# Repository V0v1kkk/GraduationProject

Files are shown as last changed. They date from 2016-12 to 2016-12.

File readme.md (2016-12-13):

# Разработка аппаратно-программного комплекса для оперативного мониторинга качества воздуха в жилых помещениях
Цель работы – разработать аппаратно-программный комплекс, с помощью которого можно оперативно получать данные о качестве воздуха, параметрах микроклимата, содержании монооксида углерода, двуокиси углерода, взвешенных частиц и природного газа в воздухе жилых помещений.

В процессе работы: 
* Изучена предметная область.
* Рассмотрены аналоги разработанного устройства, представленные на рынке. 
* Произведён выбор датчиков, наиболее подходящих для использования в устройстве, 
    а также рассмотрены вопросы, связанные с получением корректных данных от них. 
* Построена [диаграмма потоков данных](Images/DFD.png).
* Разработана [принципиальная схема устройства](Images/схема.png). 
* Разработаны прошивки для двух микроконтроллеров, 
    входящих в состав устройства (**[1](DataCollector/), [2](MainController/)**). 
* Разработан [графический интерфейс](Images/Интерфейс.png), представленный [ЖК-дисплеем](Nextion/) (**[1](Images/gui/1.png), [2](Images/gui/2.png), [3](Images/gui/3.png), [4](Images/gui/4.png), [5](Images/gui/5.png), [6](Images/gui/6.png), [7](Images/gui/7.png), [8](Images/gui/8.png), [9](Images/gui/9.png), [10](Images/10.png)**) и 
[web-интерфейс](WebInterface/) (**[1](Images/1.png), [2](Images/2.png), [3](Images/3.png), [4](Images/4.png), [5](Images/5.png)**). 
* Написано руководство пользователя. 
* Построен прототип устройства.

## [Пояснительная записка](Text/Диплом.pdf)

## Видео
Прототип в работе (https://www.youtube.com/watch?v=i2k4qLWkXlE)

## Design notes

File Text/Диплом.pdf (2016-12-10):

Министерство образования и науки Российской Федерации ФГАОУ ВО «Уральский федеральный университет имени первого Президента России Б.Н.Ельцина» Институт радиоэлектроники и информационных технологий – РТФ Кафедра радиоэлектроники информационных систем

Допустить к защите в ГЭК

Зав. кафедрой ____РЭИС___

______________ С.В. Поршнев
Подпись | Ф И О
«______» ____________________ 2016 г.

### РАЗРАБОТКА АППАРАТНО-ПРОГРАММНОГО

### КОМПЛЕКСА ДЛЯ ОПЕРАТИВНОГО МОНИТОРИНГА

### КАЧЕСТВА ВОЗДУХА В ЖИЛЫХ ПОМЕЩЕНИЯХ

ВЫПУСКНАЯ КВАЛИФИКАЦИОННАЯ РАБОТА Пояснительная записка
230201 000 000 717 ПЗ

Руководитель

Н. Т. Сафиуллин

Консультант

С. А. Поташникова

Консультант

М. Д. Комаров

Нормоконтролер

В.Ф. Кочкина

Студент

РЗ-600407 | В. И. Рогожин

Екатеринбург

2016

СОДЕРЖАНИЕ

ОБОСНОВАНИЕ ЗАТРАТ НА ПРОЕКТИРОВАНИЕ И ИЗГОТОВЛЕНИЕ

7.5 Выводы по разделу | 109
ЗАКЛЮЧЕНИЕ | 111
СПИСОК ИСПОЛЬЗОВАННЫХ ИСТОЧНИКОВ | 113
ПРИЛОЖЕНИЕ А ЛИСТИНГ ЧАСТИ ИСХОДНОГО КОДА ПРОШИВКИ
МИКРОКОНТРОЛЛЕРА СБОРА ДАННЫХ | 122
ПРИЛОЖЕНИЕ Б ЛИСТИНГ ЧАСТИ ИСХОДНОГО КОДА БИБЛИОТЕКИ
RUNNINGAVARAGE | 126
ПРИЛОЖЕНИЕ В ФОРМАТ «ОБЩЕНИЯ» С МОДУЛЕМ ZE07-CO И
ДАТЧИКОМ MH-Z14 | 128
ПРИЛОЖЕНИЕ Г ЛИСТИНГ ЧАСТИ ИСХОДНОГО КОДА ПРОШИВКИ
ОСНОВНОГО МИКРОКОНТРОЛЛЕРА | 129
ПРИЛОЖЕНИЕ Д ЛИСТИНГ ЧАСТИ JAVASCRIPT КОДА ДЛЯ ВЗАИМОДЕЙСТВИЯ WEB-ИНТЕРФЕЙСА С МИКРОКОНТРОЛЛЕРОМ
| 142

Разраб.; Пров.; Н.контр.; Утв.; Изм.; Лист.; № докум.; Подп.; Дата.; Лит.; Лист; Листов; Кочкина В.Ф; УрФУ, ИРИТ-РТФ, РЗ-600407; Разработка аппаратно-программного комплекса для оперативного мониторинга качества воздуха в жилых помещениях Пояснительная записка; Рогожин В.И; Сафиуллин Н.Т; Поршнев С.В

Подп. и дата Взаим. инв. № Инв. № дубл Подп. и дата Инв. № подл.

РЕФЕРАТ

Пояснительная записка содержит 145 стр., 22 табл., 44 рис., 5 приложений, 94 библ. названия.
РАЗРАБОТКА АППАРАТНО-ПРОГРАММНОГО КОПЛЕКСА ДЛЯ ОПЕРАТИВНОГО МОНИТОРИНГА КАЧЕСТВА ВОЗДУХА В ЖИЛЫХ ПОМЕЩЕНИЯХ
Цель работы – разработать аппаратно-программный комплекс, с помощью которого можно оперативно получать данные о качестве воздуха, параметрах микроклимата, содержании монооксида углерода, двуокиси углерода, взвешенных частиц и природного газа в воздухе жилых помещений. Изучена предметная область, рассмотрены аналоги разработанного устройства, представленные на рынке. Произведён выбор датчиков, наиболее подходящих для использования в устройстве, а также рассмотрены вопросы, связанные с получением корректных данных от них. Разработана принципиальная схема устройства. Разработаны прошивки для двух микроконтроллеров, входящих в состав устройства. Разработан графический интерфейс, представленный ЖК-дисплеем и web-интерфейс. Написано руководство пользователя. Построен прототип устройства.
В работе рассмотрены вопросы безопасности жизнедеятельности. В экономическом разделе дипломного проекта оценены затраты на проведение НИР, рассмотрен вопрос привлечения инвестиций, рассчитана итоговая стоимость устройства из расчёта партии в сто штук.

ПЕРЕЧЕНЬ ЛИСТОВ ГРАФИЧЕСКИХ ДОКУМЕНТОВ

№ п/п | Наименование документа | Обозначение документа | Формат
1 | Аппаратно-программный комплекс для оперативного мониторинга качества воздуха в жилых помещениях. Схема электрическая принципиальная. | 230201.000.000.717 Э3 | А3

ПЕРЕЧЕНЬ СОКРАЩЕНИЙ

FIFO – (акроним First In, First Out — «первым пришёл — первым ушёл»)

– способ организации и манипулирования данными относительно времени и

приоритетов. Это выражение описывает принцип технической обработки

очереди или обслуживания конфликтных требований путём упорядочения

процесса по принципу: «первым пришёл — первым обслужен» (ПППО). Тот,

кто приходит первым, тот и обслуживается первым, пришедший следующим

ждёт, пока обслуживание первого не будет закончено, и так далее [1].

REST – (сокр. от англ. Representational State Transfer – «передача

состояния | представления») | – | архитектурный | стиль | взаимодействия

компонентов распределённого приложения в сети. REST представляет собой

согласованный набор ограничений, учитываемых при проектировании

распределённой системы [2].

MQTT – (сокр. от англ. Message Queue Telemetry Transport) – лёгкий

сетевой протокол, работающий поверх TCP/IP. Используется для обмена

сообщения между устройствами по принципу издатель-подписчик [3].

UART – (сокр. от англ. Universal Asynchronous Receiver-Transmitter –

универсальный асинхронный приёмопередатчик) – узел вычислительных

устройств, предназначенный для организации связи с другими цифровыми

устройствами. Преобразует передаваемые данные в последовательный вид

так, чтобы было возможно передать их по цифровой линии другому

аналогичному устройству [4].

JSON – (сокр. от англ. JavaScript Object Notation) – простой формат

обмена данными, удобный для чтения и написания как человеком, так и

компьютером. Он основан на подмножестве языка программирования

JavaScript, определенного в стандарте ECMA-262 3rd Edition - December 1999

[5].

URI – (сокр. от англ. Uniform Resource Identifier – унифицированный

(единообразный) идентификатор ресурса) – последовательность символов,

идентифицирующая | абстрактный | или | физический | ресурс. | Является

надмножеством URL [6].

ВВЕДЕНИЕ

В процессе своей жизнедеятельности человек постоянно соприкасается

со многими факторами внешней среды, и эти факторы, естественно,

оказывают на организм человека определенное влияние. Одним из таких

факторов является воздушная среда. Воздух играет важную роль в обмене

веществ в человеческом организме. Поэтому важным фактором в обеспечении

здоровья и хорошего самочувствия человека является наличие чистого и

комфортного по своим характеристикам воздуха.

Повышенное содержание некоторых газов в воздухе способно оказывать

значительное воздействие на здоровье человека, и даже угрожать жизни. Так

же некоторые газы, бытовое применение которых широко распространено

взрывоопасны.

В связи с этим, актуальность работы состоит в обеспечении людей,

находящихся в жилых помещениях оперативной информацией о качестве

воздуха, которыми они дышат, и связана с сохранностью их жизни и здоровья.

ПОСТАНОВКА ЗАДАЧИ

Цель работы: разработать аппаратно-программный комплекс, с

помощью которого можно оперативно получать данные о качестве воздуха,

параметрах микроклимата, содержании монооксида углерода, двуокиси

углерода, взвешенных частиц и природного газа в воздухе жилых помещений.

Разработанное устройство позволит предупреждать людей, находящихся в

жилых помещениях об отклонениях отслеживаемых показателей от нормы,

тем самым предотвращая возможные негативные последствия для жизни и

здоровья людей. Так же устройство должно иметь возможность передавать

собранные данные, что позволит получать и анализировать данные внешними

информационными системами, поддерживающими выбранный протокол.

Для достижения поставленной цели требуется:

- Изучить предметная область.
- Рассмотреть аналоги разработанного устройства, представленные

на рынке.

- Произвести выбор датчиков для использования в устройстве.
- Рассмотреть вопросы, связанные с получением корректных

данных от выбранных датчиков.

- Разработать принципиальную схему устройства.
- Разработать прошивки для микроконтроллеров, входящих в

состав устройства.

- Разработать интерфейс пользователя.
- Написать руководство пользователя.
- Построить прототип устройства.

АНАЛИЗ ПРЕДМЕТНОЙ ОБЛАСТИ

Системы мониторинга качества воздуха жилых помещений ещё не

получили широкого распространения, но, с учётом последних тенденций в

обществе, интерес к устройствам, позволяющим улучшить качество жизни и

повысить её безопасность неуклонно растёт. В ответ на общественный запрос

разрабатывается аппаратура, позволяющая предупреждать пользователей об

опасных отклонениях в составе и качестве воздуха.

В | настоящее | время | на | рынке | потребительской | электроники

насчитывается порядка нескольких десятков различных устройств подобной

направленности. В основном, в данных устройствах делается упор на

мониторинг | температуры | и | влажности (микроклимата), | мониторинг

содержания углекислого газа. Некоторые устройства в дополнение к

параметрам микроклимата и содержания углекислого газа позволяют

отслеживать концентрацию такого опасного для человека газа, как монооксид

углерода, а также концентрацию взвешенных частиц в воздухе. Среди

отечественных компаний подобные устройства производит только компания

Даджет.

В отношении интерфейса большинство производителей принимают

решение или ограничиться цветовой индикацией на устройстве и перенести

пользовательский интерфейс в мобильное приложение, как в устройстве от

компании Airboxlab (рисунок 2.1), или выводить информацию на ЖК дисплей

и отказаться от дополнительных интерфейсов, как в устройстве «Монитор

качества воздуха» от компании Даджет (рисунок 2.2) [7].

Общим минусом всех представленных на рынке устройств является их

высокая стоимость. Стоимость всех подобных устройств, возможности

которых не ограничиваются мониторингом только одного показателя, выше 8

тысяч рублей.

Так же на рынке довольно широко представлен другой класс устройств

– погодные станции. Большинство устройств данного класса позволяют отслеживать только температуру и влажность, и в более редких случаях,

атмосферное давление.

Сравнение | возможностей | и | приблизительной | стоимости

разрабатываемого устройства и четырёх наиболее популярных устройств,

представленных на рынке приведено в таблице 2.1. Так как погодные станции

относятся к другому классу устройств, сравнение с ними не производится.

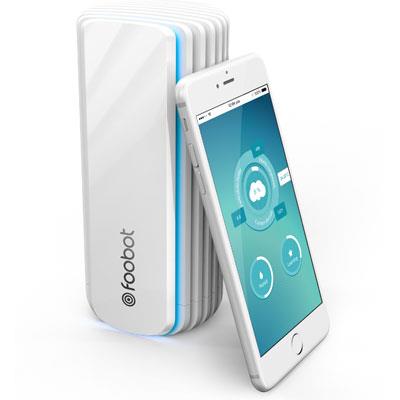
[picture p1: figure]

Рисунок 2.1 – «Foobot» от компании Airboxlab

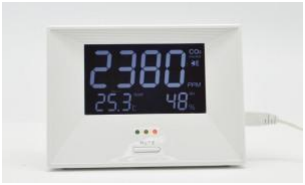
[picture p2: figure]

Рисунок 2.2 – «Монитор качества воздуха» от компании Даджет

Таблица 2.1 – Сравнение возможностей разрабатываемого устройства с аналогами

| Разрабатываемое устройство | Даджет «Монитор качества воздуха» [7] | Airboxlab «Foobot» [8] | Birdi [9] | Koto Air [10]
Мониторинг температуры/влажности | Да | Да | Да | Да | Да
Мониторинг содержания CO2 в воздухе | Да | Да | Да | Да | Да
Мониторинг содержания CO в воздухе | Да | Нет | Да | Да | Нет
Мониторинг содержания взвешенных части в воздухе | Да | Нет | Да | Да | Да
Детектирование утечек природного газа | Да | Нет | Да | Нет | Нет
Звуковые оповещения | Да | Да | Нет | Да | Нет
Графический интерфейс | Да | Да | Нет | Нет | Нет
Дополнительные возможности | Передача данных по протоколу MQTT | | Изменяющаяся подсветка устройства, мобильные приложения, интеграция с социальными сетями | Изменяющаяся подсветка устройства, мобильные приложения, возможность работы от батарей, мониторинг яркости освещения | Изменяющаяся подсветка устройства, мобильные приложения, мониторинг яркости освещения, мониторинг атмосферного давления, мониторинг уровня шума
Ориентировочная цена | 12 261,24 ₽ | 8 950 ₽ | 13 007,39 ₽ (199 $) | 7 778,29 ₽ (119 $) | 9 085,56 ₽ (139 $)

СТРУКТУРА УСТРОЙСТВА

### 3.1 Выбор оборудования

### 3.1.1 Выбор датчиков газа

Следует отметить, что большинство датчиков газов, предлагаемых на

рынке, можно разделить по принципу работы на три типа:

1. инфракрасные (на основе недисперсионной ИК-спектрометрии);
2. электрохимические;
3. полупроводниковые.

Принцип работы инфракрасных датчиков основан на изменении

интенсивности инфракрасного излучения до и после поглощения газа.

Измеряется количество света, прошедшего через светофильтр и поглощенного

газом. После сравнения с показателями потока светового излучения,

прошедшего мимо оптического устройства, датчик определяет разницу и

выдает итоговый показатель концентрации газа. К преимуществам данного

вида | датчиков | можно | отнести | высокую | стабильностью, | хорошую

избирательностью, отсутствие зависимости от содержания в воздухе

кислорода [11]. К недостаткам можно более высокую стоимость по сравнению

с электрохимическими и полупроводниковыми датчиками.

Электрохимические датчики позволяют определять концентрацию газа

в смеси газов по значению электрической проводимости раствора,

поглотившего этот газ. Чувствительным элементом датчика является

электрохимический сенсор, состоящий из трех электродов, помещенных в

сосуд с электролитом. Чувствительность к различным компонентам

определяется материалом электродов и применяемым электролитом.

Например, сенсор кислорода представляет собой гальванический элемент с

двумя электродами и является источником тока, величина которого

пропорциональна концентрации кислорода [12]. Недостатком данного типа датчиков является их чувствительность не только целевому газу, но и к

некоторым другим (зависит от конкретной модели датчика).

Чувствительный материал полупроводниковых датчиков газа — это

высокоактивный оксид металла, обычно SnO2. Когда чувствительная

поверхность датчика нагревается до определенной температуры, атомы

кислорода абсорбируются поверхностью полупроводника, насыщенного

электронами. Электроны с поверхности полупроводника захватываются

атомами кислорода, которые в результате превращаются в отрицательные

ионы кислорода. Это приводит к образованию положительно заряженных

областей на поверхности полупроводника, в результате чего увеличивается

пороговое напряжение, которое препятствует движению электронов.

Свободные электроны внутри чувствительного материала должны проходить

через | границу | полупроводника, | чтобы | формировать | ток. | Однако

абсорбированный поверхностью кристалла кислород увеличивает пороговое

напряжение, блокируя свободное перемещение электронов. Таким образом, у

датчика появляется сопротивление. В рабочем состоянии, когда присутствует

другой | газ, | вызывающий | окислительно-восстановительную | реакцию,

концентрация отрицательных ионов кислорода уменьшается. Это приводит к

уменьшению порогового напряжения, и, как следствие, к уменьшению

сопротивления датчика [13]. К преимуществам данного вида датчиков можно

отнести их крайне низкую стоимость, а к недостаткам низкую селективность.

### 3.1.1.1 Выбор датчика CO2

К вредностям, подлежащим ассимиляции системами вентиляции,

относятся газообразные загрязнители, выделяемые в процессе дыхания и через

поверхность кожи человека (аммиак, сероводород, ацетон и т. п.), а также

химические летучие соединения, выделяемые мебелью и отделочными

материалами в помещении. В процессе дыхания человека в нормальных

условиях изменению концентрации подвержены в основном два компонента

воздуха: кислород и углекислый газ. В ходе метаболических процессов в организме человека концентрация кислорода в выдыхаемом воздухе

снижается с 20,9 до 16,3 %, а углекислого газа, наоборот, возрастает с 0,03 до

4 %. Следует обратить внимание на то обстоятельство, что концентрация

углекислого газа возрастает более чем в 100 раз. Специалистами было

установлено, что степень концентрации газовых загрязнителей, выделяемых

человеком, тесно коррелируют с изменением концентрации углекислого газа,

выделяемого при дыхании человека. В этой связи концентрация углекислого

газа была принята в качестве индикатора качества воздуха. Другие вредные

газовые выделения в помещениях жилых зданий (фенолформальдегиды,

ацетон, аммиак и другие компоненты, выделяемые мебелью, отделочными

материалами) приводят к эквивалентам углекислого газа. Загрязнители от

мебели и отделочных материалов (в основном формальдегиды и анилины) по

отношению к вредностям, выделяемым человеком, носят в основном

разнонаправленный | характер | и | ассимилируются | воздухообменом,

рассчитанным по концентрации СО2 [14].

ГОСТ 30494–2011 «Здания жилые и общественные. Параметры

микроклимата в помещениях», предусматривает четыре класса качества

воздуха в помещении в зависимости от концентрации углекислого газа,

которые приведены в таблице 3.1. Средние концентрации CO2 в воздухе

приведены в таблице 3.2 [15].

Таблица 3.1 – Классы качества воздуха в зависимости от содержания

CO2

Класс | Качество воздуха в помещении | Допустимое содержание CO2*, см³ /м³
Оптимальное | Допустимое
1 | Высокое | - | 400 и менее
2 | Среднее | - | 400-600
3 | - | Допустимое | 600-1000
4 | - | Низкое | 1000 и более

* Допустимое содержание CO2 в помещениях принимают сверх содержания CO2 в наружном воздухе, см³

/м³

Таблица 3.2 – Средняя концентрация CO2 и CO в воздухе

Местность | Концентрация в воздухе
| CO2, см³ /м³ | CO, мг/м³
Сельская местность, существенные источники отсутствуют | 350 | 1
Небольшой город | 375 | 1-3
Загрязненный центр большого города | 400 | 2-6
С учётом требуемой высокой чувствительности датчика CO2 в диапазоне

от 350 до 15000 см3/м3 (в [16] вводится разовая ПДК равная 13 790 ppm и

среднесменная 4 597 ppm для воздуха рабочей зоны производственных

помещений), был выбран датчик MH-Z14 (рисунок 3.1) производства

Winsensor. Датчик относится к типу инфракрасных, что обеспечивает высокую

селективность. Датчик отличается низкой стоимостью (по сравнению с

другими инфракрасными датчиками), способен передавать данные с помощью

широтно-импульсной модуляции или через UART. К минусам данного

датчика относится низкая верхняя граница измерений, равная 10000 ppm.

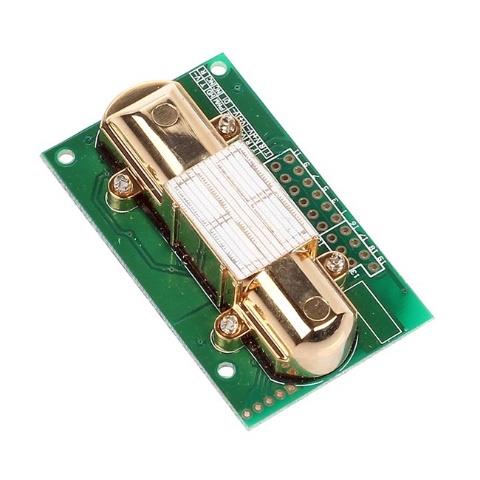
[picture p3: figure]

Рисунок 3.1 – Датчик MH-Z14

### 3.1.1.2 Выбор датчика CO

Монооксид углерода выделяется при сгорании различных веществ,

содержащих углерод.

Воздействие угарного газа СО на организм различается в зависимости

от концентрации и продолжительности воздействия, а также от состояния

здоровья конкретного человека. Приблизительно 80—90% поглощенного

оксида углерода соединяется с гемоглобином и образует карбоксигемоглобин

(HbCO), | который | является | специфичным | биологическим | маркером

воздействия (оксида углерода) на кровь. У большинства людей не будут

проявляться какие-либо симптомы при концентрации СО до 70 ppm. С

увеличением концентрации симптомы становятся заметными, это могут быть

усталость, тошнота, головная боль. В высоких концентрациях или при

длительном | воздействии | наступают | дезориентация, | головокружение,

тошнота, потеря сознания и смерть.

В помещениях жилых зданий источниками CO могут быть:

- выхлопы автомобиля в плохо проветриваемом гараже;
- неисправные отопительные приборы;
- открытый огонь или электрические отопительные приборы с

открытой горячей спиралью в помещениях, где пыльно или много

горючих паров [17].

Согласно [18] максимальная разовая ПДК монооксида углерода

равняется 17,2 ppm, при длительности работы в атмосфере, содержащей оксид

углерода, не более 1 ч предельно допустимая концентрация оксида углерода

может быть повышена до 43 ppm, при длительности работы не более 30 мин -

до 86 ppm, при длительности работы не более 15 мин - 172 ppm. Повторные

работы при условиях повышенного содержания оксида углерода в воздухе

рабочей зоны могут проводиться с перерывом не менее, чем в 2 ч. Согласно

[19] концентрация HbCO в крови более 2,5% может оказывать негативное

влияние на здоровье человека, повышать риск развития сердечно-сосудистых

заболеваний. В связи с этим приводятся рекомендации по максимальному

содержанию оксида углерода в воздухе, при которых концентрация HbCO в крови человека не превысит 2,5%, даже при выполнении лёгкой или

умеренной физической работы:

- 100 мг/м3 (90 ppm) в течение 15 минут;
- 60 мг/м3 (50 ppm) в течение 30 минут;
- 30 мг/м3 (25 ppm) в течение 1 часа;
- 10мг/м3 (10 ppm) в течение 8 часов.

С учётом озвученных выше требований был выбран датчик окиси

углерода ME2-CO производства Winsen. Датчик относится к типу

электрохимических, обладает высокой чувствительность к оксиду углерода,

«паразитной» чувствительностью к водороду и этилену. Датчик позволяет

измерять концентрацию оксида углерода в интервале от 0 до 1000 ppm.

Предпосылками к выбору именно этого датчика являлось то, что повышенные

концентрации водорода и этилена в помещениях жилых зданий маловероятны,

полупроводниковые датчики не обеспечивают однозначности полученных

данных, а инфракрасные датчики оксида углерода исключительно редки. Для

исключения проблем с калибровкой датчика, датчик решено использовать в

составе модуля Z07-CO (рисунок 3.2) производства всё той же компании

Winsen. Модуль проходит калибровку на заводе, отдаёт получаемые данные

по UART.

Рисунок 3.2 – Модуль Z07-CO

### 3.1.1.3 Выбор датчика утечки «бытового газа»

Природный газ, по-прежнему, используется во многих жилых домах и

квартирах в качестве дешевого и практичного топлива. Однако утечка газа

может представлять огромную опасность для людей. Газ не только является

отравляющим веществом, он может гореть и в закрытом помещении стать

причиной взрыва. Чистый пропан запахом не обладает, поэтому чтобы

распознать опасность вовремя, добавляют в него специальную отдушку. Но,

даже не смотря на специфический запах бытового пропана, человек может

вовремя не распознать утечку, по причине насморка, или пребывая во сне. Так

же взрывоопасная воздушно-газовая смесь может образоваться до того, как

человек почувствует запах газа.

В качестве датчика пропана был выбран полупроводниковый датчик

MQ-4. Датчик обладает высокой степенью чувствительности к сниженным

углеводородным газам и метану, и, в меньшей степени, к водороду, оксиду

углерода, спирту и дыму. Чувствительность датчика ко многим другим

веществам, не даёт полностью однозначно интерпретировать получаемые

данные при низких концентрациях пропана, но при больших концентрациях

(более 400 ppm), можно с большой уверенностью делать выводы о

повышенном содержании пропана в воздухе. Выбор был сделан в пользу

данного датчика в силу того, что датчик очень дешев, возможности

детектировать присутствие природного газа при концентрациях выше 400 ppm

вполне достаточно, так как взрывоопасные концентрации пропана лежат в

диапазоне от 21000 ppm до 95000 ppm. Датчик решено использовать в составе

модуля FC-22 (рисунок 3.3), где предварительно установлен нагрузочный

резистор.

### 3.1.2 Выбор дополнительных датчиков

### 3.1.2.1 Выбор датчика температуры и влажности

Все жизненные процессы в организме сопровождаются непрерывным

выделением теплоты в окружающую среду. Для нормального протекания физиологических процессов необходимо, чтобы выделяемая организмом

теплота полностью отводилась в окружающую среду. Нарушение теплового

баланса может привести к перегреву или переохлаждению. Следует отметить,

что при небольших отклонениях физических факторов воздушной среды от

зоны комфорта самочувствие здоровых людей может не измениться, в то

время как у больных людей часто возникают, так называемые, метеотропные

реакции. Особенно чувствительны к изменению метеорологических факторов

внешней | среды | люди, | страдающие | сердечно-сосудистыми, | нервно-

психическими и простудными заболеваниями. Оптимальный микроклимат -

такое сочетание его параметров, которое при воздействии на человека в

течение длительного времени обеспечивает тепловой баланс организма,

точнее примерное равенство между величиной теплопродукции организма

человека и его теплоотдачей в окружающую среду. Оптимальный

микроклимат обеспечивает ощущение комфорта и создает предпосылки для

высокого уровня работоспособности [20].

Рисунок 3.3 – Модуль FC-22 с датчиком MQ-4

Допустимые параметры температуры и влажности в помещениях жилых

зданий регламентируются ГОСТ 30494-2011 «Здания жилые и общественные.

Параметры микроклимата в помещениях» [15]. Оптимальные и допустимые

нормы температуры и относительной влажности в обслуживаемой зоне

помещений жилых зданий и общежитий приведены в таблице 3.3. Согласно

ГОСТ [15], теплым называется период года с температурой выше +8°С,

холодным - с температурой ниже или равной +8°С.

Таблица 3.3 – Оптимальные и допустимые параметры микроклимата

Период года | Температура воздуха, °С | Относительная влажность, %
оптимальная | допустимая | оптимальная | допустимая не более
Холодный | 20-22 | 18-24 | 45-30 | 60
Теплый | 22-25 | 20-28 | 60-30 | 65

В качестве датчика температуры и влажности был выбран датчик

AM2302 (DHT22) производства Aosong (рисунок 3.4). Предпочтение было

отдано именно этому датчику в силу его невысокой стоимости, компактности,

возможности съёма показаний при использовании только одного вывода

микроконтроллера.

Рисунок 3.4 – Датчик AM2302

### 3.1.2.2 Выбор датчика взвешенных частиц

Взвешенные частицы (РМ или particulate matter) представляют собой

широко распространенный загрязнитель атмосферного воздуха, включающий

смесь твердых и жидких частиц, находящихся в воздухе во взвешенном

состоянии. К показателям, которые обычно используются для характеристики

РМ и имеют значение для здоровья, относятся массовая концентрация частиц

диаметром менее 10 мкм (PM10) и частиц диаметром менее 2,5 мкм (PM2,5). В

PM2,5, которые часто называют мелкодисперсными взвешенными частицами,

также входят ультрамелкодисперсные частицы диаметром менее 0,1 мкм [21].

По имеющимся оценкам, при увеличении концентрации РМ10 на 10 мкг/м³
суточная смертность от всех причин возрастает на 0,2–0,6% [22, 23]. В

условиях хронической экспозиции РМ2,5 каждое повышение концентрации РМ2,5 на 10 мкг/м³
сопряжено с ростом долговременного риска

кардиопульмональной смертности на 6–13% [24, 25, 26, 21].

Особенно уязвимыми являются чувствительные группы людей,

страдающих заболеваниями легких или сердца, а также люди пожилого

возраста и дети. Например, подверженность воздействию РМ отрицательно

влияет на развитие легких у детей, приводя, в частности, к обратимым

нарушениям легочной функции, а также к хроническому замедлению темпов

роста легких и долговременной недостаточности легочной функции [27, 21].

В | Российской | федерации | предельно | допустимое | содержание

взвешенных частиц неопределённого состава регламентируется только

гигиеническими нормами ГН 2.1.6.1338-03 «Предельно допустимые

концентрации (ПДК) загрязняющих веществ в атмосферном воздухе

населенных мест» [18]. Документом [18] устанавливается максимальная разовая концентрация равная 0,5 мг/м³
, максимальная среднесуточная концентрация равная 0,15 мг/м³
, размер фракции не регламентируется.

Выбор датчика взвешенных частиц сделан в пользу датчика

GP2Y1010AU0F производства компании Sharp (рисунок 3.5). Датчик является

оптическим, как и большинство бюджетных датчиков взвешенных частиц.

Инфракрасный диод и фототранзистор расположены по диагонали и

способствуют обнаружению отраженного света частиц пыли в воздухе.

Выходной сигнал датчика представляет собой аналоговое напряжение

пропорциональное | измеренной | плотности | пыли. | Датчик | хорошо

обнаруживает частицы диаметром более 0.8мкм, и даже сигаретный дым [28].

Рисунок 3.5 – Датчик GP2Y1010AU0F

### 3.1.3 Выбор микроконтроллеров

### 3.1.3.1 Выбор основного микроконтроллера

В качестве основного микроконтроллера было решено использовать

микроконтроллер ESP8266 производства Espressif systems. Выбор данного

микроконтроллера обусловлен тем, что микроконтроллер обладает очень

невысокой стоимостью при высокой тактовой частоте и большом объёме

оперативной памяти, имеет встроенный wi-fi модуль. Так же стоит отметить,

что существует множество модулей на основе данного чипа. Модули

отличаются количеством разведённых «ножек», размером flash памяти.

Для использования в устройстве был выбран модуль ESP-12E

(рисунок 3.6). Модуль обладает следующими характеристиками:

- питание 3,3 В;
- поддержка w-fi сетей 802.11 b/g/n;
- поддержка протоколов SPI, UART;
- встроенный процессор RISC (с частотой 160 МГц);
- 3 мегабайта flash памяти;
- встроенный стек TCP/IP;
- 14 дБм выходной мощности при использовании 802.11n;
- температурный диапазон -40 … 125° C;
- 12 линий ввода/вывода;

- 1 аналоговый вход (8 бит АЦП);
- 80 Кбайт оперативной памяти [29].

Рисунок 3.6 – Модуль ESP-12E

### 3.1.3.2 Выбор дополнительного микроконтроллера

Так как часть выводов модуля ESP-12E зарезервировано под служебные

нужды, четыре вывода заняты SD-картой, подключённой через SPI интерфейс,

возникла необходимость в дополнительном контроллере для сбора данных.

В качестве дополнительного контроллера был выбран микроконтроллер

ATmega328P. Выбор данного микроконтроллера обусловлен тем, что он

дёшев, обладает 21 линией ввода/вывода (при подключённом кварцевом

резонаторе), что достаточно для подключения всех выбранных датчиков,

обладает | достаточным | объёмом | flash | и | оперативной | памяти | для

программирования сложной логики.

### 3.1.4 Выбор дополнительного оборудования

### 3.1.4.1 Выбор схемы согласования уровней

Так как микроконтроллер ESP8266 питается от 3,3В, а ATmega328P от 5

В, для обеспечения безопасной связи между ними необходимо применение

конвертора уровней. Двумя наиболее популярными решениями этой

проблемы являются:

- использования | специальных | микросхем | (например,

TXB0108PWR);

- использование MOSFET транзисторов.

Преимуществом | использования | специализированных | микросхем

является то, что они позволяют согласовывать сразу множество линий

одновременно, но только между двумя опорными напряжениями. Но выбор

был сделан в пользу второго варианта (взяты транзисторы BSS138). Выбор

обусловлен тем, что в документации к датчику CO указано, что «высокий»

уровень сигнала при взаимодействии с ним по протоколу UART не должен

быть выше 3 В, что делает необходимым согласование только ещё одной

линии с другим напряжением. Так как задача согласовывать большое

количество линий не стоит, имеется три разных опорных напряжения,

MOSFET транзисторы более дёшевы, следовательно, выбор в пользу

транзисторов очевиден.

### 3.1.4.2 Выбор оборудования для вывода звука

Наиболее простым способом реализовать вывод звуковых оповещений –

использование | готовых | решений | в | виде | модулей. | Наиболее

распространёнными решениями являются модули WTV020-SD производства

Guangzhou Waytronic Technology и подули DFPlayer Mini производства

DFRobot. Вторые выгодно отличаются от первых поддержкой формата mp3,

наличием встроенного усилителя, при незначительной разнице в цене. В связи

с этим, предпочтение было отдано модулю DFPlayer Mini.

Характеристики модуля:

- напряжение питания: 3,3–5 В;
- количество каналов: 1 (моно, 3 Вт) + 2 (стерео, без усилителя);
- поддерживаемые частоты дискретизации: 8, 11,025, 12, 16, 22,05,

24, 32, 44,1, 48 кГц;

- разрядность ЦАП: 24 бита;
- отношение сигнал/шум: до 85 дБ;
- поддерживаемые файловые системы: FAT16, FAT32;
- максимальный объём SD-карты: 32 ГБ;
- форматы аудиофайлов: MP3, WAV, WMA [30].

### 3.1.4.3 Выбор ЖК-дисплея

В качестве ЖК-дисплея был выбран дисплей «Nextion» диагональю 2,4

дюйма от компании «ITEAD». Выбор в пользу этого дисплея сделан по

причине того, что этот дисплей переносит большую часть вычислений,

необходимых для вывода информации, на свою сторону, максимально снижая

нагрузку на микроконтроллер.

Взаимодействие с ЖК-дисплеем построено на приеме и отправке

данных по UART протоколу в виде простых команд. Такая простота

взаимодействия с дисплеем обусловлена тем, что графический интерфейс

вместе | со | шрифтами, | скриптами | и | глобальными | переменными

разрабатывается отдельно в ПО Nextion Editor, после чего загружается в

память дисплея.

### 3.2 Схема движения информации

Для визуализации движения информации внутри устройства и

формализации взаимодействия с пользователем была построена диаграмма

потоков данных (DFD-диаграмма). Диаграмма приведена на рисунке 3.7.

### 3.3 Принципиальная схема устройства

Для создания принципиальной схемы и разводки платы использовался

Eagle CAD, в силу того, что для него существует большое количества

пользовательских библиотек с электронными компонентами, а также

пользовательских программных модулей.

При | проектировании | схемы, | кроме | стандартной | библиотеки

компонентов использовались библиотеки Adafruit [31], DFPlayer [32],

SparkFun [33] и ESP8266 [34]. Для выбранных ранее датчиков были созданы

собственные компоненты, объединены в отдельную библиотеку.

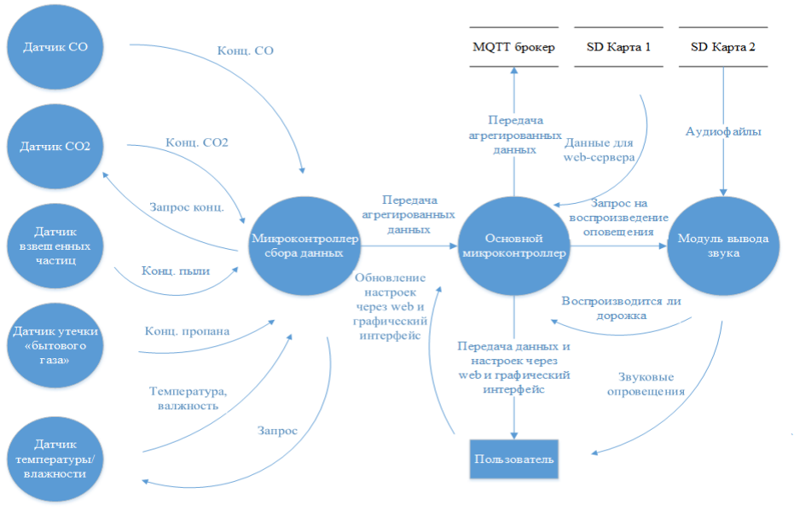
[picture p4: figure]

Рисунок 3.7 – Диаграмма потоков данных в разрабатываемом устройстве

### 3.3.1 Схема подключения микроконтроллеров

### 3.3.1.1 Схема подключения основного микроконтроллера

Модуль ESP-12E подключён согласно [29] (рисунок 3.8). Тактовая

кнопка S1 служит для «ручной» перезагрузки микроконтроллера.

Коннектор J1 используется для первичной загрузки прошивки в

микроконтроллер. | Перед | загрузкой, | программатор | перезагружает

микроконтроллер, подтягивая порт RESET к земле, переводит контроллер в

режим загрузки подтягивая порт GPIO0 к земле. Загрузка осуществляется по

UART протоколу.

Согласно [29] для запуска микроконтроллера в рабочем режиме

необходимо обеспечить высокий уровень на GPIO0 и GPIO2, низкий на

GPIO15, после чего данные порты можно использовать в других целях. При

подаче низкого уровня на ножку CH_PD, микроконтроллер отключается,

поэтому в нашем случае на неё всегда подаётся логическая 1.

Ножка ADC является входом АЦП, и может быть оставлена

неподключенной. Шесть ножек модуля ESP-12E, изображенных на рисунке

3.2 на нижней грани, задействованы для подключения внутренней flash памяти

и недоступны для использования.

### 3.3.1.2 Схема подключения дополнительного микроконтроллера

Микроконтроллер Atmega328P подключён согласно [35] (рисунок 3.9).

В микроконтроллер предварительно прошит загрузчик optiboot [36],

позволяющий загружать прошивку по UART протоколу. Порт J2 предназначен

для загрузки прошивки в контроллер. Для увеличения стабильности работы

микроконтроллера установлены конденсаторы C9 и С10. Для повышения

быстродействия, контроллер тактируется от внешнего кварцевого резонатора

на 16МГц.

Согласно документации к микроконтроллеру [37], подключение

оставшихся ножек не является обязательным, и их можно оставить

«висящими» в воздухе.

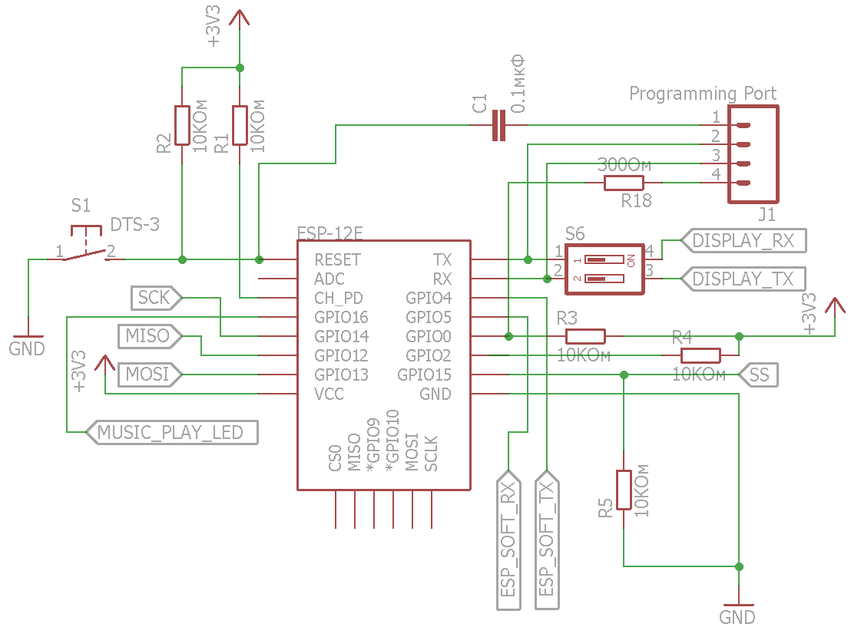
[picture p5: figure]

Рисунок 3.8 – Схема подключения модуля ESP-12E

Так как основной и дополнительный микроконтроллеры работают с

разными напряжениями, для установления надёжной связи между ними

необходимо применение схемы согласования уровней (рисунок 3.10). Такая

схема конвертора уровней является универсальной, и обеспечивает

двунаправленное соединение без модификации схемы. В исходном состоянии

ни одно из устройств не подтягивает линию связи к "0", на стороне 3,3В

устройства линия подтянута к "1" резистором R7, на стороне 5В устройства

линия подтянута к "1" резистором R8, затвор и исток транзистора имеют

одинаковый потенциал 3,3В, транзистор закрыт. Таким образом, на входе

обоих устройств присутствует логическая "1", для каждого со своим уровнем напряжения. В случае, когда 3,3В устройство устанавливает на своем выходе

"0", исток транзистора принимает низкий потенциал, в то время как на затворе

остается 3,3В, транзистор открывается, вход 5В устройства подтягивается к

низкому уровню через открытый транзистор, на входе 5В устройства

устанавливается логический "0". В последнем случае, когда 5В устройство

устанавливает на своем выходе "0", через диодный переход исток-подложка

транзистора напряжение на истоке снижается до тех пор, пока напряжение на

затворе не перейдет пороговый уровень, затем транзистор открывается и вход

3,3В устройства подтягивается к "0" открывшимся транзистором [38].

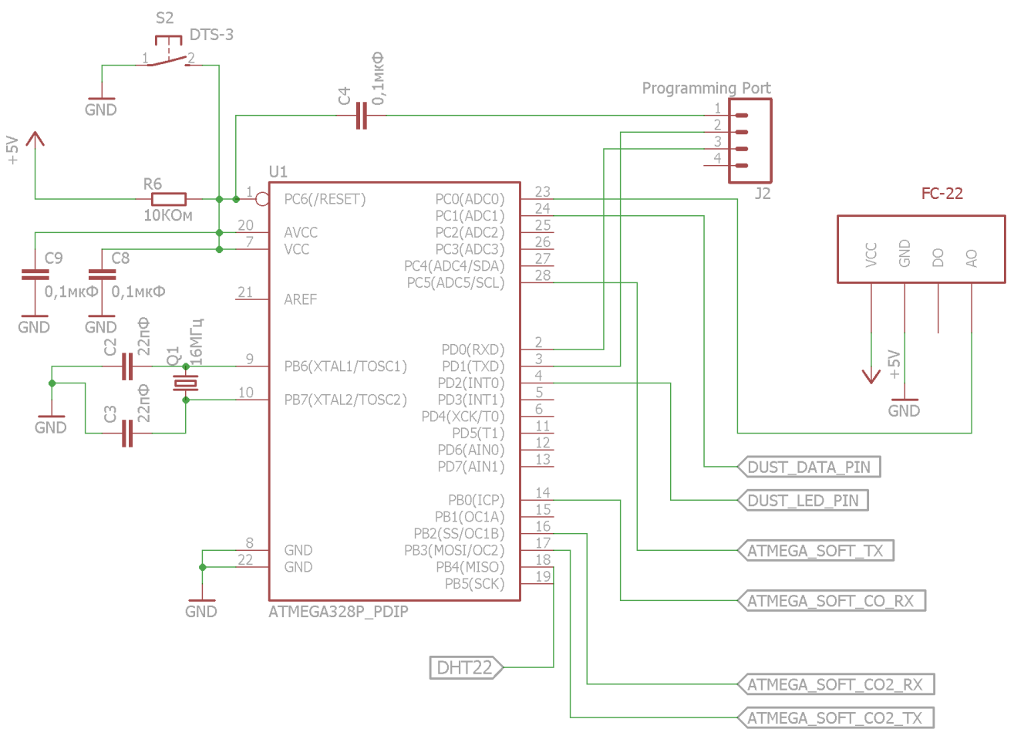
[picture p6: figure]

Рисунок 3.9 – Схема подключения микроконтроллера ATmega328

### 3.3.2 Схема подключения датчиков

### 3.3.2.1 Схема подключения датчика MH-Z14

Датчик углекислого газа MH-Z14 подключён к микроконтроллеру

ATmega328P по UART интерфейсу через конвертер уровней, так как

документацией к датчику [39] не рекомендуется высокий уровень сигнала

выше 3,5В. Схема конвертера уровней схожа с той, что изображена на рисунке

3.10, за исключением использования низкого уровня в 3В. Датчик работает по

принципу «запрос - ответ», следовательно, необходимо подключение обоих

линий UART. Подключение датчика изображено на рисунке 3.11.

Рисунок 3.10 – Схема конвертера уровней

Рисунок 3.11 – Схема подключения датчика MH-Z14

### 3.3.2.2 Схема подключения модуля ZE07-CO

Согласно документации [40], модуль имеет возможность передавать

информацию о концентрации угарного газа по протоколу UART. В режиме

«по умолчанию» модуль отправляет данные с периодичностью в 1 секунду.

Недостатком этого модуля является то, что максимальный уровень

напряжения при общении по UART протоколу не должен превышать 3В.

Однако, необходимости в дополнительном линейном стабилизаторе нет, так

как модуль обладает встроенным стабилизатором, вывод которого выведен на

одну из ножек модуля. Схема конвертера уровней полностью идентична схеме

конвертера, через который подключён предыдущий датчик. С учётом того, что

модуль способен отдавать данные без запроса, с цель упрощения схемы и

уменьшения затрат на электронные компоненты, подключение RX линии

модуля не производилось. Схема подключения приведена на рисунке 3.12.

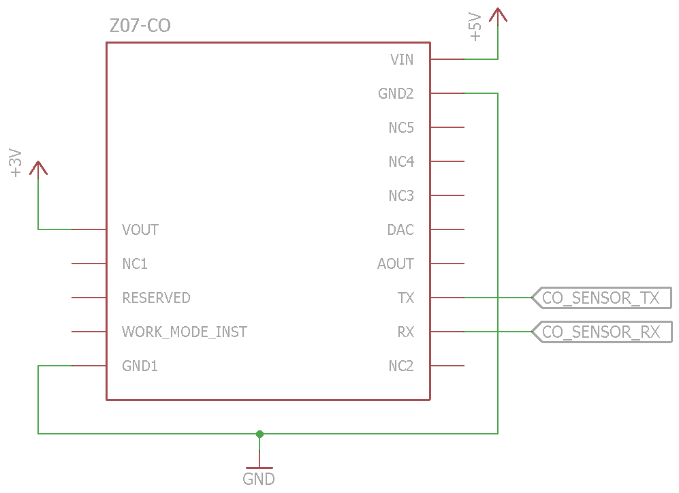
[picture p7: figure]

Рисунок 3.12 – Схема подключения модуля ZE07-CO

### 3.3.2.3 Схема подключения модуля FC-22

Модуль FC-22 имеет два выхода: цифровой и аналоговый. На цифровом

выводе устанавливается логическая 1 при превышении заданного порога

(задаётся подстрочным резистором). Так как данный способ получения

данных от датчика не позволяет точно выставить порог срабатывания, принято

решение использовать аналоговый выход модуля, анализировать полученные

данные с помощью микроконтроллера. Схема подключения датчика

приведена на рисунке 3.9.

### 3.3.2.4 Схема подключения датчика AM2302

Датчик | AM2302, | как | было | сказано | ранее, | подключается | к

микроконтроллеру с помощью одной шины данных. Из дополнительных

компонентов, согласно документации [41], необходим подтягивающий к

питанию резистор на 10КОм (R19). Схема подключения датчика приведена на

рисунке 3.13.

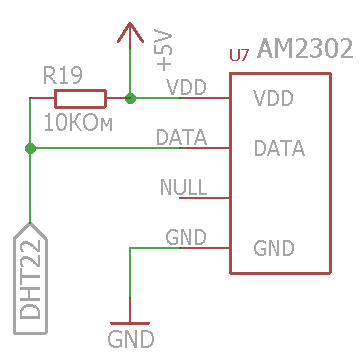
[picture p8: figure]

Рисунок 3.13 – Схема подключения датчика AM2303

### 3.3.2.5 Схема подключения датчика GP2Y1010AU0F

Датчик взвешенных частиц GP2Y1010AU0F имеет отдельное питание

инфракрасного диода и фототранзистора. Документацией к датчику [42]

рекомендуется | подключать | питание | инфракрасного | диода | через

токоограничительный | резистор | (R15), | использовать | фильтрующий

конденсатор (C5) для повышения стабильности работы датчика.

Включением и выключением диода управляет микроконтроллер,

результирующе напряжение на фототранзисторе снимается с ножки VO.

Схема подключения датчика приведена на рисунке 3.14.

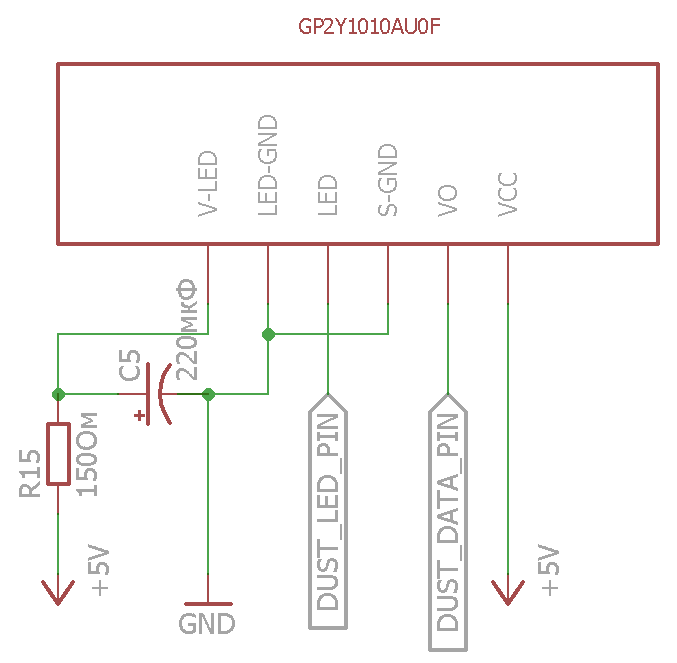
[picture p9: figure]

Рисунок 3.14 – Схема подключения датчика GP2Y1010AU0F

### 3.3.3 Схема подключения дополнительного оборудования

### 3.3.3.1 Схема подключения SD-карты

SD карта (Secure Digital Memory Card) представляет собой

микроконтроллер и микросхему flash памяти. SD карта может работать в двух

режимах:

- режим SD (собственный протокол обмена данными);
- режим SPI (в качестве интерфейса SD карта использует SPI).

Так как микроконтроллер ESP8266 имеет аппаратную поддержку

протокола SPI, SD карта будет подключаться напрямую к контроллеру, при

этом никаких дополнительных электронный компонентов не требуется.

Изображение контактов SD карты приведено на рисунке 3.15. Карта,

использующаяся в устройстве, имеет формат microSD (в силу большей

распространённости). Карты формата microSD имеют те же самые контактные

площадки, что и карты SD, но меньшей площади. Подключение

осуществляется через переходник.

Рисунок 3.15 – Контакты SD карты

Контакты SD карты имеют следующее назначение:

- DO – контакт для получения данных с SD карты;
- DI – контакт для приёма данных SD картой;
- SCLK – контакт для синхроимпульсов;
- CS – контакт «выбор ведомого»;
- Vss – земля;
- Vdd – контакт питания, от 2.7 до 3.6 В [43].

### 3.3.3.2 Схема подключения модуля DFPlayer Mini

Модуль воспроизведения звука DFPlayer Mini поддерживает несколько

режимов управления воспроизведением, как через UART интерфейс, так и с

помощью подачи импульсов на специальные выводы модуля. В данном случае

используется однонаправленное UART соединение между ESP-12E и модулем

воспроизведения звука. В документации к DFPlayer Mini [44] указано, что уровень напряжения на RX ножке не должен превышать 3,3В, что позволяет

обойтись без использования конвертера логических уровней.

Модуль имеет специальный вывод, на котором устанавливается

логическая 1, когда модуль простаивает, и логический 0, когда модуль

воспроизводит файл. Периодическое считывание состояния данного вывода

является наиболее простым способом реализовать последовательное

воспроизведение файлов с помощью микроконтроллера, поэтому данный

вывод был подключён к одному из выводов модуля ESP-12E.

ПРОГРАММНАЯ СОСТАВЛЯЮЩАЯ

Для написания прошивок для микроконтроллеров был выбран язык

wiring, позволяющий максимально абстрагироваться от особенностей

архитектуры и настройки микроконтроллеров. Язык wiring по сути

представляет собой «обёртку» над языком C (библиотеки к нему пишут на

C++), скрывающей низкоуровневую работу с микроконтроллером.

Минусом использования этого языка является то, что любая, даже самая

простая программа, написанная на этом языке, занимает больше места во flash

памяти микроконтроллера, чем программа, написанная на чистом C. Это

происходит в силу того, что код написанный на языке wiring транслируется в

код на C, при этом «подтягивая» дополнительные библиотеки. Но, так как

выбранные ранее микроконтроллеры обладают довольно большим объёмом

flash памяти, этот минус не играет большой роли и покрывается выигрышем в

скорости разработки.

Для написания кода на языке wiring используется IDE Visual Studio с

установленным дополнением Visual Micro. Выбор IDE обусловлен тем, что

данная IDE поддерживает технологию IntelliSense (автодополнение кода), что

значительно увеличивает скорость разработки.

### 4.1 Разработка прошивки для микроконтроллера сбора данных

Для периодического опроса датчиков было реализовано некое подобие

планировщика. В первую очередь производится проверка, не переполнился ли

счётчик миллисекунд, пошедших со старта микроконтроллера, что

происходит примерно каждые 50 дней безостановочной работы. После чего

происходит проверка для каждого датчика, не прошел ли интервал опроса,

заданный в структуре с настройками. Если интервал прошел – датчик

опрашивается, после чего записывается время последнего опроса.

Аналогичным образом, раз в секунду «запланирован» сбор строки с

данными для основного микроконтроллера, а также её отправка через

программный UART (используется библиотека SoftwareSerial [45]).

В структуре с настройками хранятся следующие данные:

- количество отсчётов в фильтре низких частот;
- время «прогрева» датчика;
- интервал между опросами датчика.

Часть исходного кода прошивки микроконтроллера сбора данных

приведена в приложении А.

### 4.1.1 Выбор метода первичной обработки данных

Все используемые датчики обладают высокой чувствительностью, что

приводит к высокочастотному колебанию получаемых значений, так как

параметры окружающей среды зачастую подвержены незначительным

колебаниям.

Для фильтрации данных колебаний было решено использовать

скользящее среднее (фильтр низких частот). Суть метода заключается в том,

что искомая величина получается путем усреднения нескольких значений,

непосредственно примыкающих к "центральному" значению текущей группы.

Группы получают постепенно, с шагом, равным единице, сдвигаясь от

начального значения; группа (интервал сглаживания, его называют иногда

“окном”) как бы скользит по ряду с шагом, равным единице [46].

Формула для вычисления скользящего среднего имеет вид:

SMAt =

1
n

× ∑pt−1 =

pt + pt−1 + ⋯ + pt−n+2 + pt−n+1
n

n−1

i=0

(4.1)

где SMAt — значение простого скользящего среднего в точке t;

n — количество значений исходной функции для расчёта скользящего

среднего (сглаживающий интервал), чем шире сглаживающий интервал, тем

более плавным получается график функции;

pt−1 — значение исходной функции в точке t − 1 [47].

Из предыдущего своего значения простое скользящее среднее может

быть получено по следующей рекуррентной формуле:

SMAt = SMAt−1 −

pt−n
n

+

pt
n

(4.2)

где SMAt — значение простого скользящего среднего в точке t;

SMAt−1 — предыдущее значение простого скользящего среднего;

pt−n — значение исходной функции в точке t − n, pt — значение

исследуемой функции в точке t.

Данной формулой удобно пользоваться, чтобы избежать регулярного

суммирования всех значений [47, 48].

Чтобы определить степень точности полученных данных, необходимо

оценить величину ошибки, которая может случайно произойти в процессе

измерения. | Такая | ошибка | носит | название | случайной | ошибки
репрезентативности | (m), | или | статистической | стандартной | ошибкой

выборочного среднего арифметического. Она фактически является разностью

между средними числами, полученными при выборочном статистическом

наблюдении, и аналогичными величинами, которые были бы получены при

сплошном исследовании того же объекта (т. е. при исследовании генеральной

совокупности). Ошибки репрезентативности вытекают из самой сущности

выборочного исследования. С помощью ошибок репрезентативности

числовые характеристики выборочной совокупности распространяются на

всю генеральную совокупность, то есть она характеризуется с учетом

определенной | погрешности. | Величины | ошибок | репрезентативности

определяются как объемом выборки, так и разнообразием признака. Чем больше число наблюдений, тем меньше ошибка, чем больше изменчив

признак, тем больше величина статистической ошибки. На практике для

определения средней ошибки выборки в статистических исследованиях

используются следующая формула:

m =

σ
√n

(4.3)

где m — ошибка репрезентативности;

σ — среднее квадратическое отклонение;

n — число наблюдений в выборке (при числе наблюдений менее 30 в

подкоренное выражение вносится значение n-1) [49].

В написанной прошивке подкоренное выражение в формуле (4.3)

корректируется автоматически, в зависимости от количества отсчётов в

скользящем среднем для каждого конкретного параметра.

Среднее квадратическое отклонение характеризует среднее отклонение

всех вариант вариационного ряда от средней арифметической величины.

Поскольку отклонения вариаций от среднего имеют значения с «+» и «-», то

при суммировании они взаимоуничтожаются. Чтобы избежать этого,

отклонения возводятся во вторую степень, а затем, после определенных

вычислений, производится обратное действие — извлечение корня

квадратного. Поэтому среднее отклонение именуется квадратическим [49].

Среднее квадратическое отклонение определяют по формуле:

σ = √
1
n∑(xi − x̅)
2

n

i=1

(4.4)

где σ — среднее квадратическое отклонение;

n — число наблюдений в выборке;

xi — i-й элемент выборки;

x̅— среднее арифметическое выборки [50].

Реализовывать скользящее среднее на языке с нуля не пришлось. Была

найдена библиотека «RunningAverage» [51, 52], реализующая быстрое

вычисление скользящего среднего. Данная библиотека была дополнена

методами для вычисления среднеквадратичного отклонения и стандартной

ошибки. Часть исходного кода библиотеки и реализованные методы

приведены в приложении А.

### 4.1.2 Получение данных о концентрации CO

Как было отмечено ранее, модуль ZE07-CO в режиме «по умолчанию»

отправляет данные о концентрации угарного газа с интервалом в 1 секунду,

поэтому работа с датчиком осуществляется следующим образом:

1. пропускаются все данные, которые есть в буфере программного UARTа,

так как там могут содержатся фрагментированные данные;

2. ожидается следующий пакет данных от модуля;
3. данные считываются;
4. проверяется контрольная сумма данных;
5. если контрольная сумма совпала, данные передаются для вычисления

скользящего среднего.

Пакеты с данными которые отправляет модуль состоят из 9 байт

(таблица В 1), содержат контрольную сумму, которая вычисляется следующим

образом:

NOT(байт1 + байт2 + … + байт7) + 1 | (4.5)

Концентрация угарного газа вычисляется по формуле:

(«Верхний» канал × 256 + «нижний» канал) × 0,1 | (4.6)

### 4.1.3 Получение данных о концентрации CO2

Согласно документации к датчику MH-Z14 [39], для получения данных

о концентрации CO2 по протоколу UART, необходимо отправить датчику запрос из 9 байт, на который датчик должен ответить так же 9 байтами (формат

общения с датчиком приведён в таблицах В 2 и В 3). Последний байт в запросе

и ответе является проверочным и вычисляется по формуле 4.5.

Значение концентрации CO2 можно вычисляется из ответа по формуле:

«Верхний» канал × 256 + «нижний» канал | (4.7)

Работа с датчиком осуществляется следующим образом:

1. пропускаются все данные, которые есть в буфере программного UARTа,

так как там могут содержатся фрагментированные данные;

2. отправляется запрос датчику;
3. ожидается ответ;
4. данные считываются;
5. проверяется контрольная сумма данных;
6. если контрольная сумма совпала, данные передаются для вычисления

скользящего среднего.

### 4.1.4 Получение данных об утечках пропана

В модуле FC-22 датчик MQ-4 подключён к аналоговому выходу с

использованием нагрузочного резистора (1 КОм в используемом модуле),

образуя с ним делитель напряжения. В документации к датчику [53] сказано,

что итоговое значение концентрации газа находится из отношения

сопротивления датчика, к его же сопротивлению в чистом воздухе (рисунок

4.1).

Так как для определения сопротивления необходимо знать точное

значение опорного напряжения (внешнего), используется следующий метод:

1. переключаем | опорное | напряжение | на | внутреннее | (согласно
документации | к | микроконтроллеру | [37], | внутреннее | опорное

напряжение равно 1,1 В ± 0,1 В);

2. измеряем фактическое внутреннее опорное напряжение;

3. по фактическому и теоретическому значению внутреннего опорного

напряжения, зная разрядность АЦП (10 бит), вычисляем фактическое

значение внешнего опорного напряжения;

4. переключаем опорное напряжение обратно на внешнее [54].

Реализовывать описанный выше алгоритм самостоятельно не пришлось,

функция была взята из репозитория на GitHub [55].

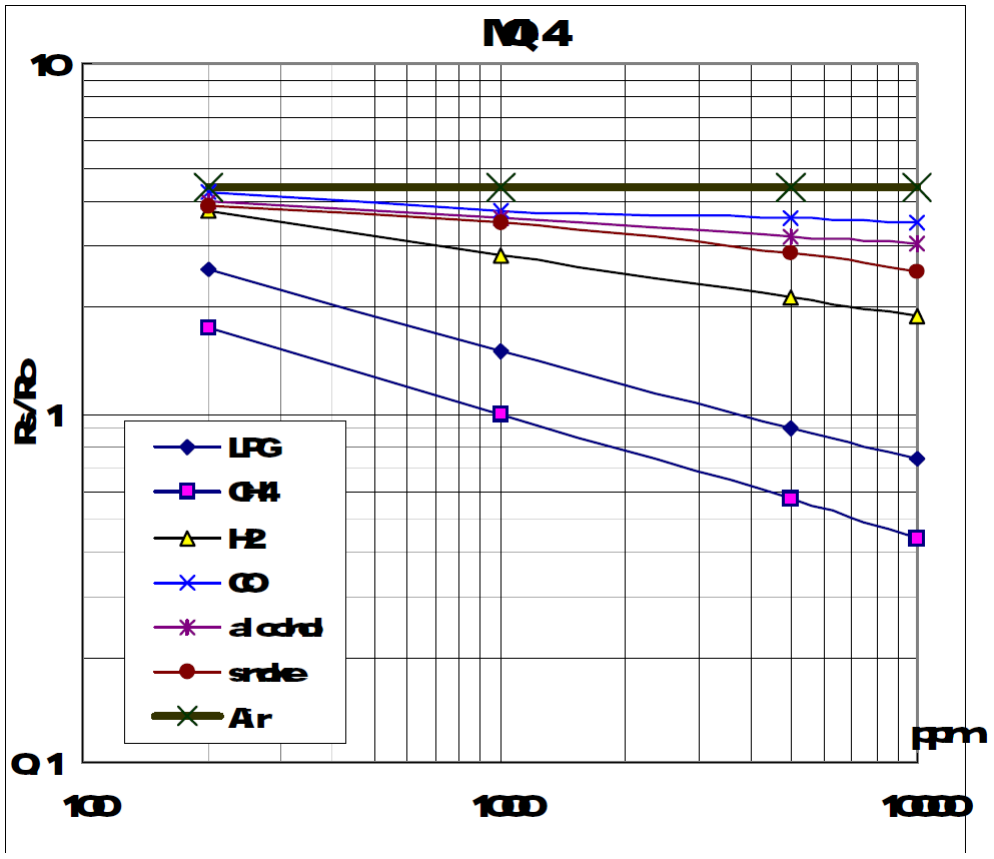
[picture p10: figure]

Рисунок 4.1 – Зависимость отношения сопротивлений датчика от

концентрации газа

Расчёт сопротивления датчика производится по следующей формуле:

RS =

vcc −

voMeasured × vcc
1023
voMeasured × vcc
1023 | ∗ RL

(4.8)

где, RS – сопротивление датчика, Ом;

vcc – внешнее опорное напряжение, В;

voMeasured – показания АЦП (от 0 до 1023);

RL – сопротивление нагрузочного резистора, Ом.

Анализ графика, приведённого на рисунке 4.1, производился с помощью

ПО WebPlotDigitizer [56]. Данное ПО позволило сделать выборку из 29 точек,

узнать их точные координаты (рисунок 4.2).

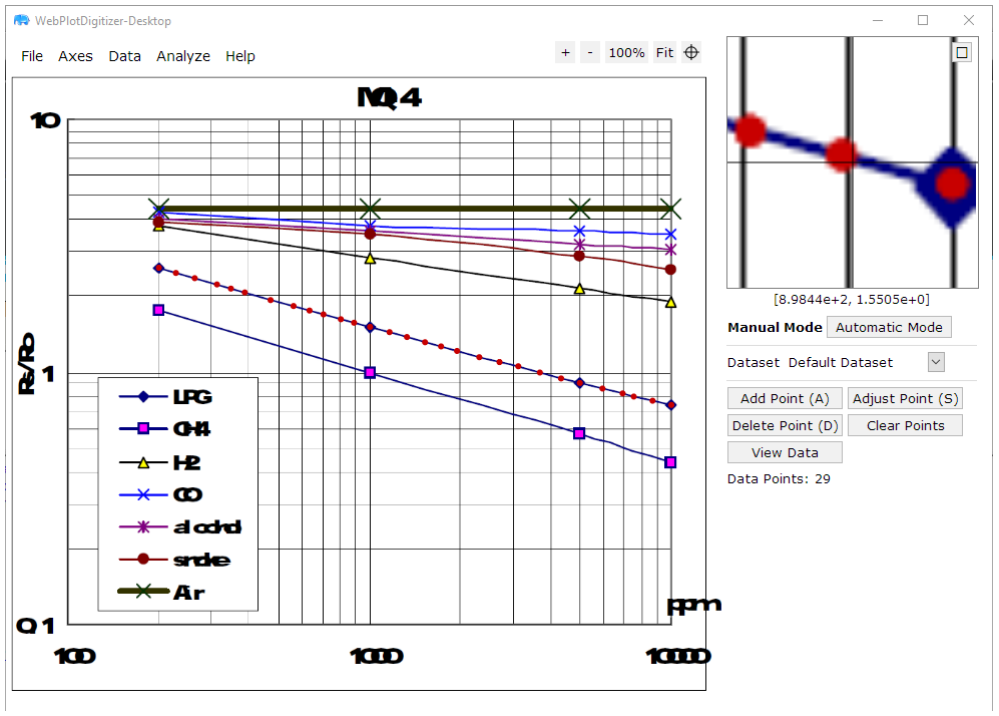
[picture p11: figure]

Рисунок 4.2 – Анализ графика в WebPlotDigitizer

Для интерполяции данных была построена степенная регрессионная

модель с помощью онлайн инструмента [57]. Итоговая интерполирующая

функция имеет вид:

Концентрация газа = 13,91826722 × (RS⁄RO)

−0,320860296 | (4.9)

Стоит отметить, что показания используемого датчика так же зависят от

температуры и влажности воздуха (рисунок 4.3). Анализ зависимости RS⁄RO

от влажности показал, что отношение изменяется практически линейно

(уменьшается на 0,00288462 с каждым 1% влажности от базового значения в

33%). Зависимость RS⁄RO от температуры изменяется нелинейно. Для

получения интерполирующей функции использовался онлайн инструмент

[58]. Получившаяся функция, описывающая коэффициент при RS⁄RO, имеет

вид:

k = 1,147618596 × e

−5,50023923×10⁻³× Temp | (4.10)

Полученные соотношения применены для корректировки данных,

полученных с помощью формулы (4.9).

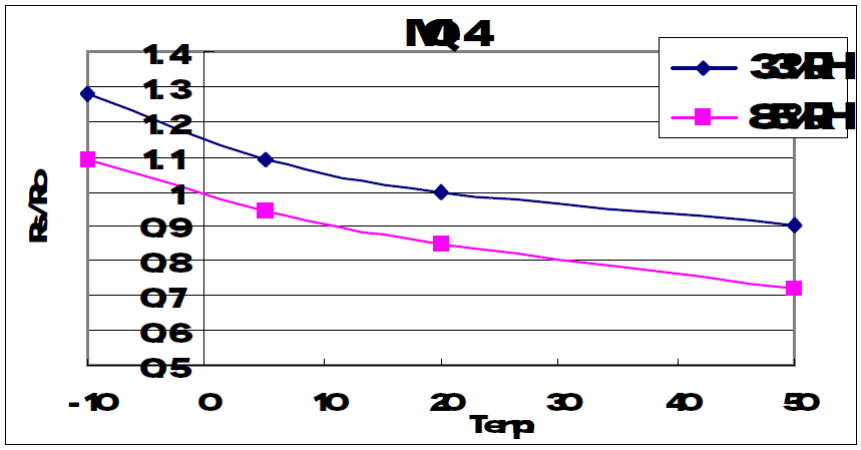
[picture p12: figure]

Рисунок 4.3 – Зависимость RS⁄RO от температуры и влажности

### 4.1.5 Получение данных о температуре и влажности

Считывание данных с датчика DHT22 осуществляется по уникальному

для данного датчика протоколу, чем-то напоминающему протокол 1-wire.

Протокол общения такой:

1. шина прижимается к 0 в течение 80мкс, после чего отпускается (это

служит меткой запроса);

2. датчик откликается удерживанием линии в 1 течение 90мкс, и начинает

передавать данные (каждый бит — это 0 в течение 50 мкс и 1 в течение

25 или 125 мкс);

3. датчик передаёт 2 байта данных влажности, 2 байта температуры и 1

байт — сумма первых 4 (CRC);

4. после завершения передачи (около 4 мс) датчик отпускает линию в

состояние 1 [59].

Для работы с данным датчиком писать собственную библиотеку не

пришлось. Для работы с датчиком была использована библиотека «DHT»

содержащаяся в стандартном наборе библиотек Arduino IDE. Библиотека

позволяет абстрагироваться от низкоуровневой работы с датчиком, получать

данные с точностью до двух знаков после запятой.

### 4.1.6 Получение данных о концентрации взвешенных частиц

Согласно документации, к датчику взвешенных частиц [42], штатный

решим работы датчика – импульсный. Светодиод внутри датчика необходимо

зажигать на не менее чем на 320 микросекунд, выдерживать паузу до

следующего включения светодиода не менее 9680 микросекунд (рисунок 4.4).

Съём показателей должен осуществляться не ранее чем через 280 микросекунд

после включения светодиода (рисунок 4.5).

Рисунок 4.4 – Минимально необходимые задержки при работе с

датчиком взвешенных частиц

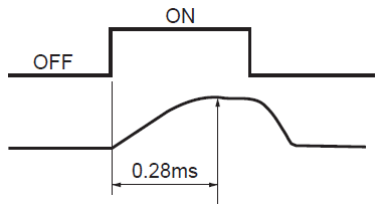
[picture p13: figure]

Рисунок 4.5 – Сравнение напряжения на датчике взвешенных частиц и

отклика датчика

Так как все описанные выше операции не занимают большого

количество времени, данный алгоритм был реализован с использованием

функции | delayMicroseconds, | которая | приостанавливает | выполнение

программы микроконтроллером на заданное количество микросекунд.

Согласно документации к датчику [42], концентрация взвешенных

частиц в воздухе связана с напряжением на выходе датчика нелинейной

зависимостью (рисунок 4.6). Для анализа графика вновь использовался

WebPlotDigitizer [56], для интерполяции применялся онлайн инструмент

(линейная регрессия) [60]. Итоговая функция имеет вид (рисунок 4.6):

y | = | 0,1672547404 × x | − | 0,09215522988 | (4.11)

где, y – концентрация взвешенных частиц, мкг/м³
;

x – напряжение на выходе датчика, В.

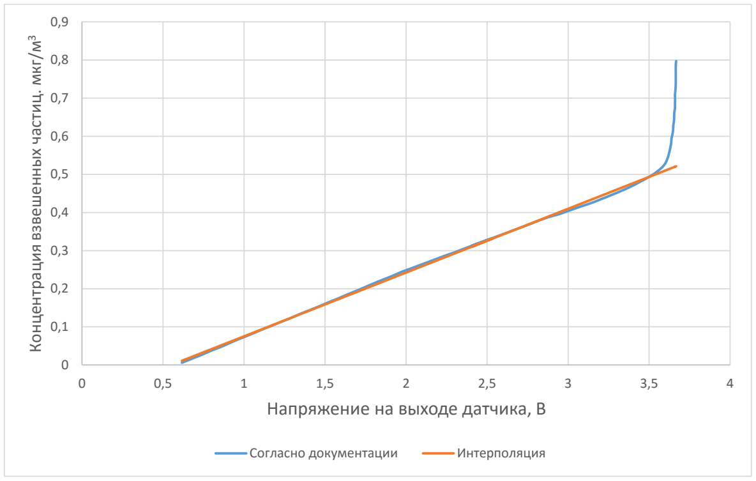
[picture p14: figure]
Концентрация взвешенных частиц. мкг/; Напряжение на выходе датчика, В; Согласно документации; Интерполяция

Рисунок 4.6 – Сравнение графиков функций, описывающих

зависимость концентрации взвешенных частиц от напряжения на выходе

датчика (согласно документации, интерполяция)

4.1.7 Формирование | данных | для | отправки | основному

микроконтроллеру

Формирование строки с данными для экономии оперативной памяти

микроконтроллера реализована с помощью C строк, хотя wiring поддерживает

строки в формате C++. Готовая к отправке строка представляется собой блоки

(по одному на каждый датчик), разделённые символом «|», и контрольную

сумму, отделённую от данных символом «*». В каждом блоке содержится от

двух до четырёх полей, разделённых символом «;», содержащие значение

скользящего среднего, а также значение стандартной ошибки. При отсутствии

данных (если буфер скользящего среднего ещё не заполнен), вместо данных

вставляется «-1».

Контрольная | сумма | вычисляется | простым | сложением | байтов,

составляющих строку, по модулю 256, что обеспечивает теоретическую

возможность обнаружения сбоев при передаче с вероятностью 256:1.

При вставке численных данных в строку с помощью функции dtostrf

возникла проблема с появлением «ведущих» пробелов, увеличивающих длину

передаваемой строки. Для решения этой проблемы была применена готовая

функция [61] для удаления лишних пробелов.

### 4.2 Разработка прошивки для основного микроконтроллера

В функционал прошивки основного микроконтроллера входит:

- получение | и | анализ | данных | от | дополнительного

микроконтроллера;

- взаимодействие с ЖК-дисплеем;
- обработка запросов к web-интерфейсу;
- отправка данных модулю воспроизведения звука;
- отправка данных на MQTT-брокер.

Настройки микроконтроллера хранятся в специальной структуре,

которая имеет следующие поля:

- имя wi-fi сети;
- пароль wi-fi сети;
- вкл./выкл. отправку данных MQTT брокеру;
- адрес MQTT-брокера;
- порт MQTT-брокера;
- логин MQTT-брокера;
- пароль MQTT-брокера;
- границы зелёной, желтой и красной зоны («уровня опасности»)

для всех отслеживаемых параметров;

- вкл./выкл. проверку, попадает ли значение параметра в

доверительный интервал 95% (если не попадает, то «уровень

опасности» изменяться не будет, оповещение не прозвучит).

Настройки при старте микроконтроллера загружаются с SD-карты, при

изменениях параметров записываются на неё же. В случае отсутствия SD-

карты, или её повреждения, будут использоваться настройки «по умолчанию»

записанные в flash памяти микроконтроллера. Для работы с файлом

конфигурации используется библиотека «ArduinoJson» [62].

В случае, если при включении устройства wi-fi сеть, заданная в

настройках не будет найдена, будет создана точка доступа с именем

«AirQuality». При подключении к ней web-интерфейс будет доступен по

адресу 192.168.4.1.

Часть исходного кода прошивки основного микроконтроллера

приведена в приложении Г.

4.2.1 Получение | и | анализ | данных | от | дополнительного

микроконтроллера

Проверка поступления данных от дополнительного микроконтроллера

производится раз в 500 миллисекунд. В первую очередь производится

проверка контрольной суммы. Если проверка успешно пройдена, строка

разбивается на блоки, а блоки на поля с данными. Разбиение производится с

помощью функции getStringPartByNr взятой из репозитория на GitHub [63].

Для хранения данных в памяти микроконтроллера используется

специальная структура, в которой хранится значение каждого отслеживаемого

параметра и его стандартной ошибки с типом float, так же с типом string. Кроме

того, для каждого отслеживаемого параметра хранится идентификатор,

показывающий в какую из зон, попадает значение параметра. Под зоной

подразумевается разделение шкалы каждого из параметров на классы по

уровню опасности.

Разделение производится на три зоны: зелёную, желтую и красную.

Границы зон «по умолчанию» заданы в соответствии с ГОСТ [15],

санитарными нормами [18, 16], но могут быть изменены через web-интерфейс.

Если после приема данных были получены какие-то новые данные (а не

только «-1»), то данные анализируются, после чего происходит их отправка на

MQTT-брокер с помощью библиотеки PubSubClient [64].

При анализе данных проверяется, в какую зону попадает значение

параметра, и, если значение попадает в красную зону, а ранее не попадало,

запрос на воспроизведение оповещения добавляется в очередь (если звуковые

оповещения включены).

### 4.2.2 Обработка запросов к web-интерфейсу

В качестве web-сервера в прошивке используется библиотека

ESP8266WebServer, входящая в состав пакета совместимости [65] для

микроконтроллеров esp8266 cо средой Arduino IDE (и языком wiring).

Для взаимодействия с пользователем через web-интерфейс в прошивке

микроконтроллера был реализован ряд обработчиков, часть из которых при

запросе определённого URI генерирует XML файл с данными, а часть

сохраняет настройки, переданные в качестве параметров.

Пример объявления обработчика:

HTTP.on("/setnetworksettings", handleSetNetworkSettings);
Пример обработчика:

{
if (HTTP.args() == 0) return; //Если параметров нет

if (HTTP.arg("SSID") != "")
{
Settings.SSIDCfg = HTTP.arg("SSID"); }
if (HTTP.arg("WifiPass") != "")
{
Settings.WifiPass = HTTP.arg("WifiPass"); }
SaveSettings();
}

### 4.2.3 Взаимодействие с модулем воспроизведения звука

Для организации очереди воспроизведения (структура FIFO) была

использована библиотека LinkedList [66].

В каждой итерации основного цикла микроконтроллер проверяет:

- выключены ли звуковые оповещения;
- пуста ли очередь воспроизведения;
- воспроизводится ли сейчас файл.

Если все три проверки закончатся отрицательно, модулю DFPlayer Mini

будет отправлено задание воспроизвести следующий файл из очереди.

Отправка задания происходит с помощью библиотеки DFPlayer-Mini-mp3 [67].

### 4.3 Разработка web-интерфейса

Web-интерфейс | устройства служит | для | настройки параметров

устройства. Через web-интерфейс так же есть возможность отслеживать

текущие показатели, собираемые устройством.

В качестве web-интерфейса используются html станицы с JavaScript

кодом. Базовый шаблон html шаблон с css стилями был взят с сайта

html5webtemplates [68], после чего частично переработан. Иконка для web-

интерфейса взята с сайта iconfinder [69]. Страница-файловый менеджер взята

из [70].

Общий алгоритм работы JavaScript кода на страницах web-интерфейса

схож. У тега «<body>» указан обработчик события «onload», который при

срабатывании выполняет запрос к заданному URI, после чего разбирает

полученные от микроконтроллера данные и заполняет ими поля формы с

настройками.

Так же обработчик события «onload» вызывает ещё одну функцию,

которая начинает вызывать сама себя с заданным интервалом. Эта функция

периодически получает от микроконтроллера данные о времени работы

микроконтроллера, а также о том, установлено ли соединение с MQTT-брокером. На главной странице дополнительно подгружаются данные о

текущих значениях отслеживаемых устройством параметрах.

Часть JavaScript кода приведена в приложении Д.

На стороне основного микроконтроллера за обработку запросов

отвечает библиотека «ESP8266WebServer» [71], часть стандартных функций

взята из примеров, поставляемых вместе с библиотекой [72].

### 4.4 Разработка графического интерфейса

Разработка графического интерфейса осуществлялась в специальной

среде разработки для экранов Nextion «Nextion Editor» [73]. Для визуализации

проектируемого интерфейса была построена схема с изображенными на ней

формами и связями между ними (рисунок 4.8).

В Nextion Editor’е были созданы окна интерфейса (рисунок 4.7), заданы

обработчики для кнопок позволяющие перемещаться между экранами. Так же

были разработаны окна с цифровой и текстовой клавиатурой (редактирование

строки данных реализовано исключительно средствами экрана). Все

остальные обработчики были заданы на стороне основного микроконтроллера.

Работа с экраном велась с использованием библиотеки NeoNextion [74].

Были созданы специальные переменные, описывающие элементы интерфейса,

с которыми будет осуществляться взаимодействие, переменным были

поставлены в соответствие обработчики, которые будут вызваны при

взаимодействии пользователя с элементом управления. Изменение какого-

либо параметра пользователем обрабатывается следующим образом:

1. при нажатии пользователя на элемент управления на стороне
микроконтроллера | вызывается | обработчик, | запоминается

идентификатор элемента;

2. пользователь | перенаправляется | на | экран | с | соответствующей

клавиатурой (c помощью триггера в интерфейсе);

3. после того, как пользователь закончил ввод данных, пользователь

перенаправляется на главный экран (c помощью триггера в интерфейсе);

4. обработчик на стороне микроконтроллера считывает поле данных (все

текстовые поля с которыми осуществляется работа, для удобства заданы

на стороне экрана как глобальные переменные), и в зависимости от

значения идентификатора, запомненного ранее, изменяется тот или

иной параметр в настройках;

5. настройки сохраняются, данные раздела, в котором был изменён

параметр, повторно записываются в переменные экрана.

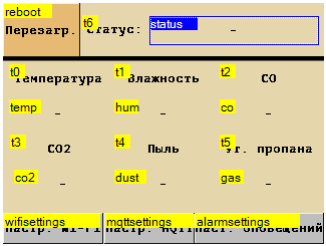
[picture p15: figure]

Рисунок 4.7 – Разработка интерфейса в Nextion Editor

Рисунок 4.8 – Схема экранов графического интерфейса и переходы между ними

РУКОВОДСТВО ПОЛЬЗОВАТЕЛЯ

### 5.1 Введение

### 5.1.1 Область применения

Данное руководство предназначено для помощи при настройке и

эксплуатации устройства пользователем.

### 5.1.2 Краткое описание возможностей

Аппаратно-программный комплекс (далее устройство) предназначен

для отслеживания следующих параметров окружающей среды:

- температура;
- влажность;
- концентрация CO2;
- концентрация CO;
- количество взвешенных частиц в воздухе.

Так же устройство способно детектировать утечки природного газа. В

случае превышения параметрами заданных показателей, а также при

выявлении утечки природного газа, способно произвести звуковое

информирование.

Устройство способно передавать собираемые данные по протоколу

MQTT для дальнейшей машинной обработки.

### 5.1.3 Уровень подготовки пользователя

Для взаимодействия с устройством через web-интерфейс необходим

опыт работы с ПО Google Chrome. Никаких дополнительных специальных

требований к пользователю системы не предъявляется.

Для настройки интеграции с другими информационными системы

пользователь должен обладать базовыми знаниями о протоколе MQTT или о

об архитектуре REST (Representational State Transfer – передача состояния

представления) взаимодействия.

### 5.2 Назначение и условия использования устройства

Устройство предназначено для предупреждения людей, находящихся в

жилых помещениях об отклонениях в отслеживаемых показателях

отгружающей среды от нормы, тем самым предотвращая возможные

негативные последствия для жизни и здоровья людей.

Так же устройство может быть использовано как поставщик данных об

окружающей среде для систем умных домов, а также для автоматизированных

систем вентиляции. Данная функция доступна только при условии того, что

устройство находится в зоне покрытия wi-fi сети, в сети есть MQTT-брокер,

автоматизированные системы способны получать данные по протоколу

MQTT.

В качестве альтернативного канала получения данных от устройства,

возможно использование http GET запросов, но в таком случае, частота

запросов не должна превышать 5 секунд. При этом одновременный доступ к

web-интерфейсу устройства с помощью браузера является нежелательным, и

может привести к замедлению работы устройства.

Устройство предназначено для эксплуатации при температуре выше 0

°С и ниже 60 °С при относительной влажности не более 70 %.

### 5.3 Подготовка к работе

### 5.3.1 Дополнительное ПО

Для настройки устройства, а также для получения данных через web-

интерфейс используется браузер Google Chrome. Он доступен для загрузки по

адресу: https://www.google.ru/chrome/browser/.

### 5.3.2 Порядок проверки работоспособности

Для проверки работоспособности устройства необходимо:

1. Подключить блок питания устройства в сеть 220 В.

2. Убедиться, что на экране устройства отобразился графический

интерфейс (рисунок 5.1).

3. В строке состояния на экране (№1 на рисунке 5.1) Должен появится

любой текст отличный от «-».

В случае возникновения проблем смотрите раздел решение проблем.

### 5.3.3 Настройка подключения к wi-fi сети

Индикатором | подключения | к | wi-fi | сети | является | квадратик

отображаемы на экране устройства (№3 на рисунке 5.1). Если подключение к

wi-fi сети было успешно, то квадратик имеет зелёный цвет, если нет, то

красный. В случае невозможности подключения к wi-fi сети устройство

создаёт открытую точку доступа с именем «AirQuality», где web-интерфейс

доступен по адресу 192.168.4.1.

Для настройки подключения через графический интерфейс необходимо:

1. Нажать на кнопку «Настр. WI-FI» на главном экране (№11 на рисунке

5.1).

2. Нажать на поле (№1 на рисунке 5.2) напротив надписи SSID.
3. При помощи появившейся клавиатуры (рисунок 5.10) ввести имя wi-fi

сети (кнопка «С» стирает введённые данные, кнопка «<<» удаляет один

символ, кнопка «St» меняет регистр клавиатуры). Подтверждение ввода

осуществляется кнопкой «OK» (№2 на рисунке 5.10).

4. Повторно нажать на кнопку «Настр. WI-FI», задать пароль от wi-fi сети

аналогичным образом (№2 на рисунке 5.2).

5. Перезагрузить устройство (№1 на рисунке 5.1).

Внимание: web-интерфейс является вторичным. Загрузка страниц

интерфейса может происходить до 2,5 минут.

Для настройки подключения через web-интерфейс необходимо:

1. Подключиться к открытой wi-fi сети «AirQuality».

2. В браузере Google Chrome перейти по адресу 192.168.4.1. Должен

отобразиться такой же интерфейс как на рисунке 5.12. Если этого не

произошло, то смотрите пункт решение проблем.

3. Перейти на страницу «Настройки сети», которая находится в панели

навигации (№1 на рисунке 5.12).

4. На странице «Настройки сети» (рисунок 5.13) ввести имя сети в поле

под номером 2, а пароль в поле номер 3, после чего нажать на кнопку

«Сохранить настройки» (№4 на рисунке 5.13).

5. Перейти на страницу «Служебное», нажать на кнопку «Перезагрузить

устройство» (№4 на рисунке 5.16).

### 5.3.4 Настройка подключения к MQTT-брокеру

Индикатором подключения к MQTT-брокеру является квадратик

отображаемы на экране устройства (№4 на рисунке 5.1). Если подключение к

MQTT-брокеру было успешно, то квадратик имеет зелёный цвет, если нет, то

красный.

Внимание: если использование функции передачи данных по протоколу

MQTT не планируется, убедитесь, что данная опция отключена. Для этого

необходимо нажать на кнопку «Настр. MQTT» на главном экране

графического интерфейса (№12 на рисунке 5.1), убедиться, что кнопка

«Выключит MQTT» (№1 на рисунке 5.3) находится во включённом состоянии.

Если настройка производится через web-интерфейс, то данную опцию можно

найти на странице «Настройки MQTT» (№2 на рисунке 5.14).

Сообщения будут публиковаться в теме «Air» в подтемах со

следующими именами:

- Temperature;
- Temperature_Error;
- Humidity;
- Humidity_Error;

- CO2;
- CO2_Error;
- CO;
- CO_Error;
- Dust;
- Dust_Error.

В подтемы с постфиксом «Error» публикуются данные о средней

ошибке соответствующего параметра.

Для настройки подключения через графический интерфейс необходимо:

1. Нажать на кнопку «Настр. MQTT» на главном экране (№12 на рисунке

5.1).

2. Последовательно нажимая на поля, помеченные как 2,3,4 и 5 на рисунке

5.3 задать параметры подключения. После задания каждого параметра

будет происходить возврат на главный экран. Необходимо выполнять

действия с первого пункта пока не будут указаны все реквизиты.

3. Если была включена опция «Выключить MQTT» (№1 на рисунке 5.2), то

её необходимо выключить.

Внимание: web-интерфейс является вторичным. Загрузка страниц

интерфейса может происходить до 2,5 минут.

Для настройки подключения через web-интерфейс необходимо:

1. В браузере Google Chrome перейти по адресу ip адресу по которому

устройство доступно в вашей сети (уточните у вашего системного

администратора) Должен отобразиться такой же интерфейс как на

рисунке 5.12. Если этого не произошло, то смотрите пункт решение

проблем.

2. Перейти на страницу «Настройки MQTT», которая находится в панели

навигации (№1 на рисунке 5.12).

3. На странице «Настройки MQTT» (рисунок 5.14) ввести реквизиты для

подключения к MQTT-брокеру (№3, №4, №5, №6 на рисунке 5.14), после

чего нажать на кнопку «Сохранить настройки» (№4 на рисунке 5.14).

4. Если была включена опция «Выключить MQTT» (№2 на рисунке 5.14),

то её необходимо выключить.

5. Если подключение к MQTT-брокеру с заданными реквизитами было

успешно, то в течение 10 секунд на панели состояния (№8 на рисунке

5.14) появится сообщение, что соединение установлено.

### 5.3.5 Настройка оповещений

Программное | обеспечение | устройства | подразделяет | значения

отслеживаемых параметров на зелёную, желтую и красную зону в зависимости

от того, в какой из установленных в настройках интервалов попадает значение

параметра. Значения параметров «по умолчанию» заданы с учётом

государственных стандартов и санитарных норм, действующих в РФ.

Если в настройках включены звуковые оповещения, то при попадании

значения отслеживаемого параметра в красную зону будет воспроизведено

голосовое оповещение.

Для уменьшения вероятности ложного срабатывания предусмотрена

статистическая | проверка, | попадет | ли | значение | параметра | в | 95%

доверительный интервал.

Настройка через графический интерфейс осуществляется через серию

экранов (рисунки 5.4 – 5.9), попасть на которую можно нажав кнопку «Настр.

оповещений» (№13 на рисунке 5.1). На первом экране (рисунок 5.4)

осуществляется включение и выключение звуковых оповещений, а также

включение и выключение статистической проверки данных. Переход к

следующему экрану в серии осуществляется с помощью кнопки «Дальше» (4

на рисунке 5.4). На всех следующих экранах в серии можно изменить границы

зон. Для этого необходимо нажать на тот параметр, который необходимо

изменить, ввести новое значение на появившейся клавиатуре (рисунок 5.11), подтвердить внесение изменений с помощью кнопки «Готово» (№5 на рисунке

5.11)

В web-интерфейсе настройка оповещений осуществляется на вкладке

«Настройки оповещений» (рисунок 5.15). Переключателями, отмеченными 2

и 3 на рисунке 5.15, осуществляется включение и выключение звуковых

оповещений, а также включение и выключение статистической проверки

данных. В поля с 4 по 31 при загрузке страницы загружаются текущие

настройки границ зон. В случае модификаций каких-либо значений или

изменении позиций переключателей сохранение изменений осуществляется

нажатием на кнопку «Сохранить настройки» (№34 на рисунке 5.15).

### 5.4 REST интерфейс устройства

Внимание: отправка запросов к устройству чаще одного раза в пять

секунд не рекомендуется!

### 5.4.1 Получение данных от устройства

Устройство отвечает на GET запросы данными в формате XML.

Поддерживаются следующие запросы:

- /xml
- /alarmsettings
- /networksettings
- /mqttsettings

### 5.4.1.1 Получение текущих значений отслеживаемых параметров

Для получения текущих значений отслеживаемых параметров

необходимо выполнить GET запрос к URI /xml. В ответе будет содержаться

текущие значения отслеживаемых параметров, а также в какую зону попадают

значения (0 – нет данных, 1 – зелёная зона, 2 – желтая зона, 3 – красная зона).

Кроме того, в ответе будут содержатся данные о времени бесперебойной

работы устройства, и о том, установлено ли соединение с MQTT-брокером (1

или 0). Пример ответа устройства:

<Result>
<uptime>01:14:41</uptime>
<Temperature>26.90</Temperature> <TemperatureState>1</TemperatureState> <Humidity>31.53</Humidity> <HumidityState>1</HumidityState> <CO2>782.00</CO2>
<CO2State>1</CO2State>
<CO>0.50</CO>
<COState>1</COState>
<Dust>0.00</Dust>
<DustState>1</DustState>
<LPGState>2</LPGState>
<MQTTConnectionStatus>1</MQTTConnectionStatus> </Result>

### 5.4.1.1.1 Получение текущих настроек сети

Для получения текущих настроек сети необходимо выполнить GET

запрос к URI /networksettings. В ответе будет содержаться текущие значения

SSID и пароля. Пример ответа устройства:

<Result>
<SSID>vovikkk</SSID>
<WifiPass>Aion1aion</WifiPass>
</Result>

### 5.4.1.2 Получение текущих настроек MQTT

Для получения текущих настроек MQTT необходимо выполнить GET

запрос к URI /mqttsettings. В ответе будет содержаться текущие значения

реквизитов для подключения к MQTT-брокеру (сервер, порт, логин, пароль), а

также включена ли передача данных по протоколу MQTT (1 или 0). Пример

ответа устройства:

<Result>
<MQTTDisabled>0</MQTTDisabled> <MQTTServer>vovikkk.ru</MQTTServer> <MQTTPort>1883</MQTTPort>
<MQTTLogin>AirMonitor</MQTTLogin> <MQTTPassword>diplom</MQTTPassword>
</Result>

### 5.4.1.3 Получение текущих настроек оповещений

Для получения текущих значений параметров, отвечающих за границы

зон, а также за выдачу звуковых оповещений необходимо выполнить GET

запрос к URI /mqttsettings. В ответе будет содержаться текущие значения

грациц зелёной, желтой и красной зоны, данные о том включены ли голосовые оповещения (1 или 0), включена ли статистическая проверка данных (1 или 0).

Пример ответа устройства:

<Result>
<AlarmState>0</AlarmState> <CheckErrorState>1</CheckErrorState> <TemperatureGreenZoneUP>28.00</TemperatureGreenZoneUP> <TemperatureGreenZoneDown>22.00</TemperatureGreenZoneDown> <TemperatureYellowZoneUP>27.00</TemperatureYellowZoneUP> <TemperatureYellowZoneDown>20.00</TemperatureYellowZoneDown> <TemperatureRedZoneUP>100.00</TemperatureRedZoneUP> <TemperatureRedZoneDown>-50.00</TemperatureRedZoneDown> <HumidityGreenZoneUP>60.00</HumidityGreenZoneUP> <HumidityGreenZoneDown>30.00</HumidityGreenZoneDown> <HumidityYellowZoneUP>65.00</HumidityYellowZoneUP> <HumidityYellowZoneDown>20.00</HumidityYellowZoneDown> <HumidityRedZoneUP>100.00</HumidityRedZoneUP> <HumidityRedZoneDown>0.00</HumidityRedZoneDown> <CO2GreenZoneUP>1400.00</CO2GreenZoneUP> <CO2GreenZoneDown>0.00</CO2GreenZoneDown> <CO2YellowZoneUP>1400.00</CO2YellowZoneUP> <CO2YellowZoneDown>1000.00</CO2YellowZoneDown> <CO2RedZoneUP>10000.00</CO2RedZoneUP> <CO2RedZoneDown>1400.00</CO2RedZoneDown> <COGreenZoneUP>2.58</COGreenZoneUP> <COGreenZoneDown>0.00</COGreenZoneDown> <COYellowZoneUP>4.30</COYellowZoneUP> <COYellowZoneDown>0.00</COYellowZoneDown> <CORedZoneUP>10000.00</CORedZoneUP> <CORedZoneDown>0.00</CORedZoneDown> <DustGreenZoneUP>0.15</DustGreenZoneUP> <DustGreenZoneDown>0.00</DustGreenZoneDown> <DustYellowZoneUP>0.50</DustYellowZoneUP> <DustYellowZoneDown>0.00</DustYellowZoneDown> <DustRedZoneUP>999.00</DustRedZoneUP> <DustRedZoneDown>0.00</DustRedZoneDown> </Result>

### 5.4.2 Изменение настроек устройства

Изменение настроек устройства осуществляется с момощью http PUT

запросов. При успешном выполнении запроса устройство ответит кодом 200:

OK, при неудачном 400: Bad Request.

### 5.4.2.1 Изменение настроек сети

Для изменения настроек сети необходимо выполнить запрос по URI

/setnetworksettings. Параметрами запроса должны являться SSID и WifiPass.

При необходимости, тот параметр изменение которого не требуется можно

опустить.

### 5.4.2.2 Изменение настроек MQTT

Для изменения настроек сети необходимо выполнить запрос по

URI /setmqttsettings. Параметрами запроса должны являться:

- disable (отключён ли MQTT, 1 или 0);
- server;
- port;
- login;
- password.

При необходимости, те параметры изменение которых не требуется

можно опустить.

### 5.4.2.3 Изменение настроек оповещений

Для изменения границ зон, а также для выключения и выключения

голосовых оповещений и статистической проверки данных необходимо

выполнить запрос по URI /setalarmsettings. Параметрами запроса должны

являться:

- AlarmState (включены ли голосовые оповещения, 1 или 0);
- CheckErrorState (включена ли статистическая проверка данных, 1

или 0);

- TGZUP (температура: верхняя граница зелёной зоны);
- TGZDown (температура: нижняя граница зелёной зоны);
- TYZUP (температура: верхняя граница желтой зоны);
- TYZDown (температура: нижняя граница желтой зоны);
- TRZUP (температура: верхняя граница красной зоны);
- TRZDown (температура: нижняя граница красной зоны);
- HGZUP (влажность: верхняя граница зелёной зоны);
- HGZDown (влажность: нижняя граница зелёной зоны);
- HYZUP (влажность: верхняя граница желтой зоны);
- HYZDown (влажность: нижняя граница желтой зоны);
- HRZUP (влажность: верхняя граница красной зоны);

- HRZDown (влажность: нижняя граница красной зоны);
- CO2GZUP (углекислый газ: верхняя граница зелёной зоны);
- CO2GZDown (углекислый газ: нижняя граница зелёной зоны);
- CO2YZUP (углекислый газ: верхняя граница желтой зоны);
- CO2YZDown (углекислый газ: нижняя граница желтой зоны);
- CO2RZUP (углекислый газ: верхняя граница красной зоны);
- CO2RZDown (углекислый газ: нижняя граница красной зоны);
- COGZUP (угарный газ: верхняя граница зелёной зоны);
- COGZDown (угарный газ: нижняя граница зелёной зоны);
- COYZUP (угарный газ: верхняя граница желтой зоны);
- COYZDown (угарный газ: нижняя граница желтой зоны);
- CORZUP (угарный газ: верхняя граница красной зоны);
- CORZDown (угарный газ: нижняя граница красной зоны);
- DGZUP (взвешенные частицы: верхняя граница зелёной зоны);
- DGZDown (взвешенные частицы: нижняя граница зелёной зоны);
- DYZUP (взвешенные частицы: верхняя граница желтой зоны);
- DYZDown (взвешенные частицы: нижняя граница желтой зоны);
- DRZUP (взвешенные частицы: верхняя граница красной зоны);
- DRZDown (взвешенные частицы: нижняя граница красной зоны).

При необходимости, те параметры изменение которых не требуется

можно опустить.

### 5.4.3 Прочие запросы

Для перезагрузки устройства может использоваться http PUT запрос по

URI /reset. В случае получения запроса устройство ответит кодом 200: OK,

после чего основной микроконтроллер будет перезагружен.

### 5.5 Решение проблем

Таблица 5.1 – Проблемы и их возможные решения

Проблема | Возможные решения
Нет индикации на экране, устройства нет в сети. | Проверить наличие питания, работоспособность блока питания.
На экране долгое время не изменяются данные, хотя в web-интерфейсе изменяются. | Перезагрузить устройство по питанию.
После изменения параметров через графический интерфейс, настройки остаются прежними. | Перезагрузить устройство по питанию.
Как вернуть настройки к состоянию «по умолчанию»? | Получить от разработчика оригинальный конфигурационный файл; В web-интерфейсе перейти на страницу «Служебное», нажать на ссылку «Загрузка файлов на SD-карту» (№3 на рисунке 5.16); Удалить файл config.jsn (нажать по файлу правой кнопкой и выбрать «Delete»); С помощью кнопки изображенной под номером 2 на рисунке 5.17 выбрать файл, полученный от разработчика; Нажать на кнопку «Upload» (4 на рисунке 5.17); Подождать 5 секунд; Перезагрузить устройство.
После изменения настроек подключения к wi-fi сети, подключение к данной сети не происходит. | Перезагрузить устройство.

В случае, если описанные в таблице 5.1 проблемы не удалось решить

указанным способом, или если проблема отсутствует в таблице свяжитесь с

разработчиком устройства.

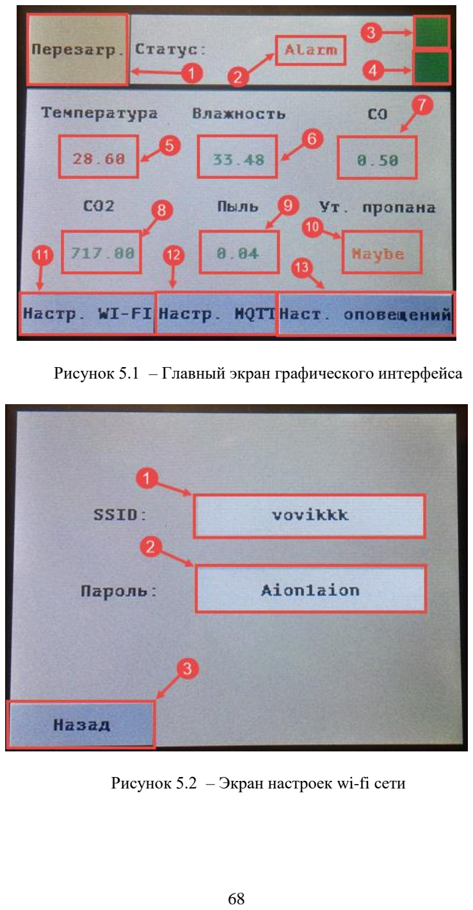
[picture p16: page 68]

Рисунок 5.1 – Главный экран графического интерфейса

Рисунок 5.2 – Экран настроек wi-fi сети

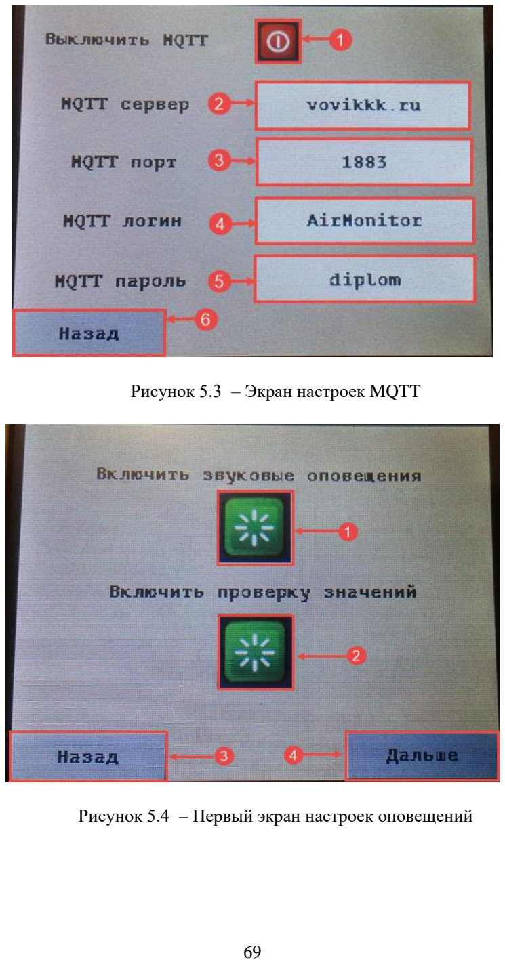
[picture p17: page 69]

Рисунок 5.3 – Экран настроек MQTT

Рисунок 5.4 – Первый экран настроек оповещений

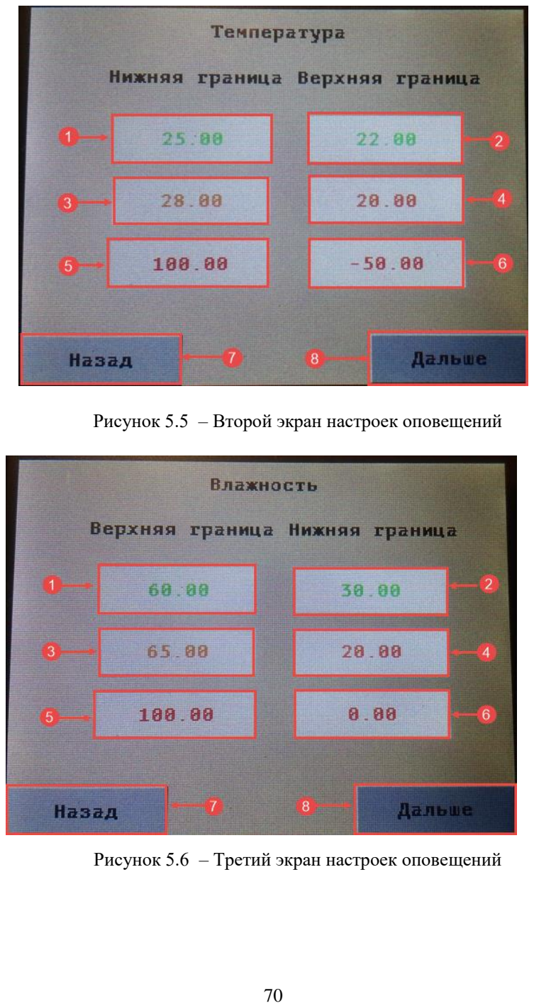
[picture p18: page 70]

Рисунок 5.5 – Второй экран настроек оповещений

Рисунок 5.6 – Третий экран настроек оповещений

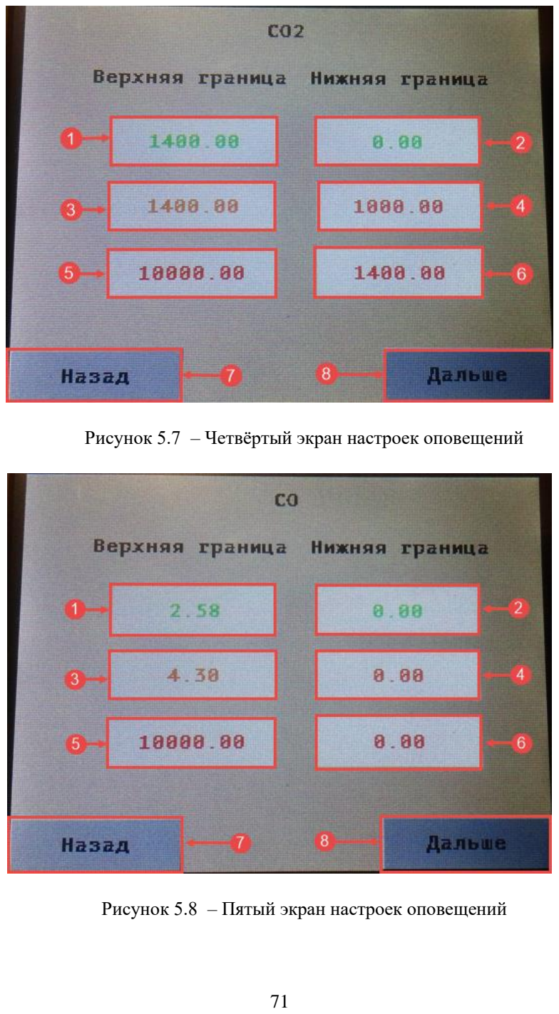
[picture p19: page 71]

Рисунок 5.7 – Четвёртый экран настроек оповещений

Рисунок 5.8 – Пятый экран настроек оповещений

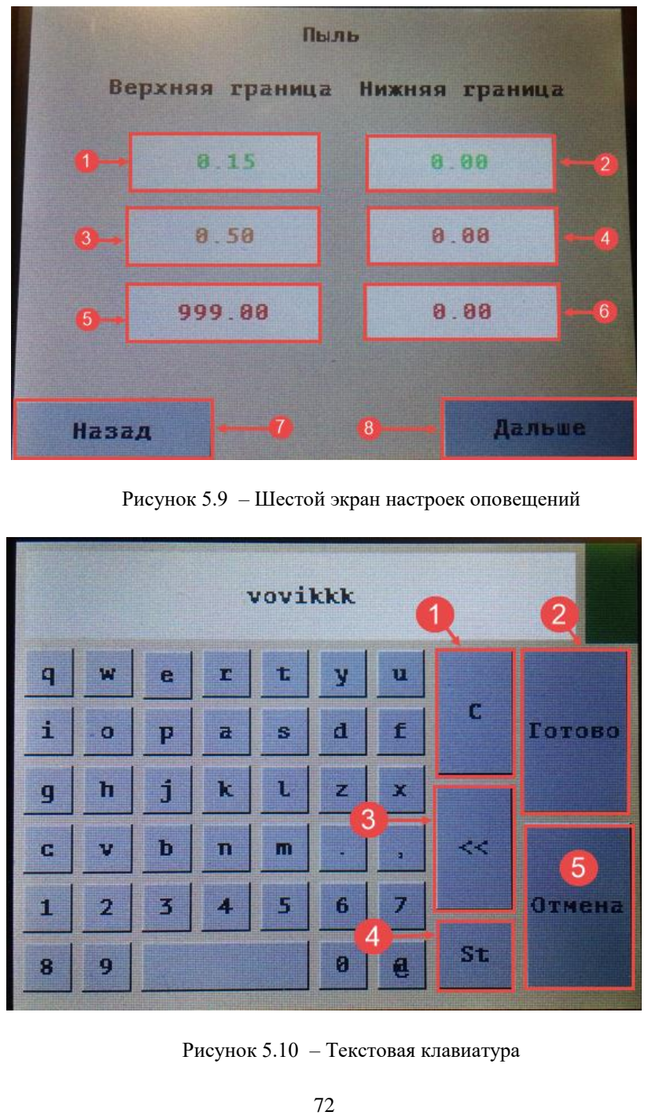
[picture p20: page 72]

Рисунок 5.9 – Шестой экран настроек оповещений

Рисунок 5.10 – Текстовая клавиатура

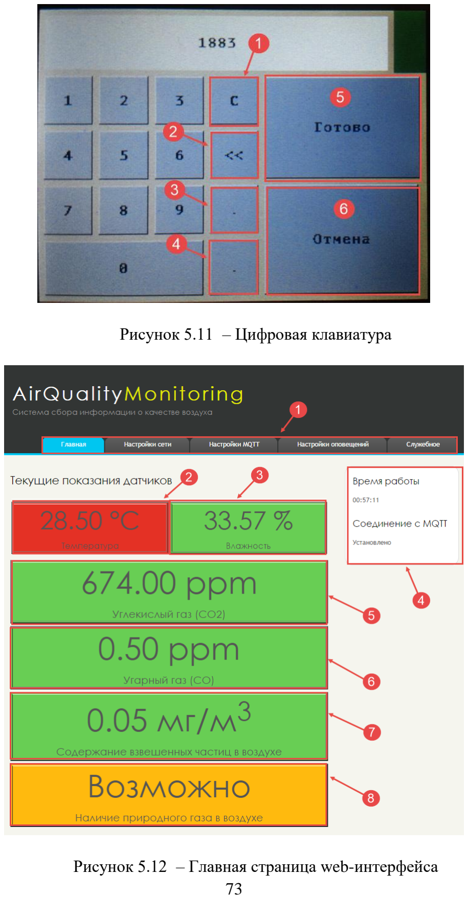
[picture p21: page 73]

Рисунок 5.11 – Цифровая клавиатура

Рисунок 5.12 – Главная страница web-интерфейса

Рисунок 5.13 – Страница настроек wi-fi сети в web-интерфейсе

Рисунок 5.14 – Страница настроек MQTT в web-интерфейсе

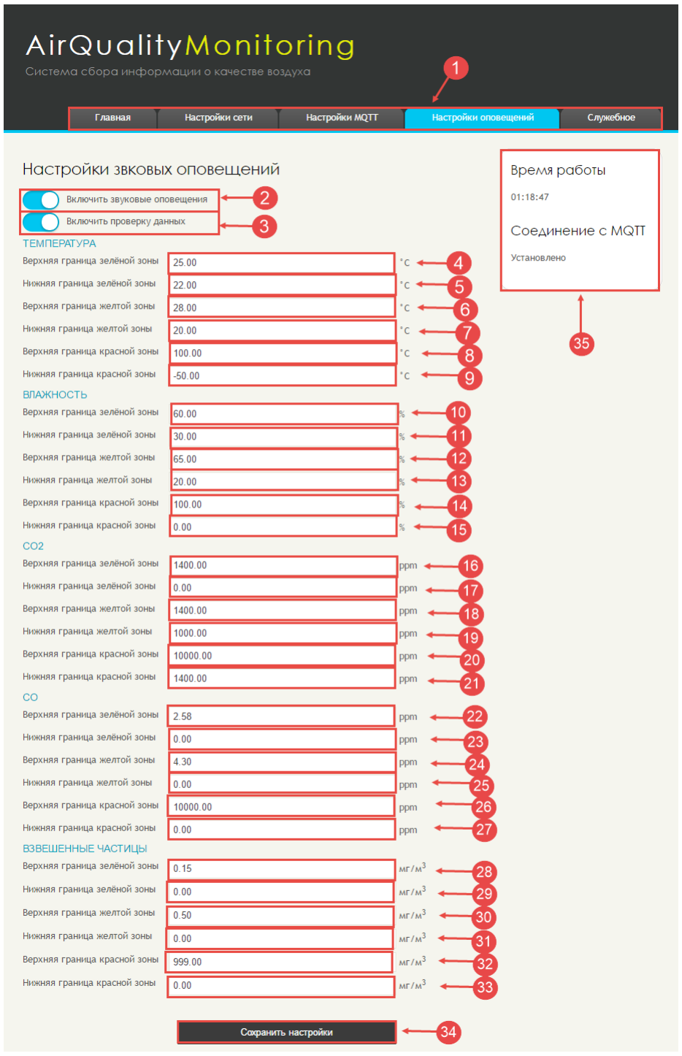
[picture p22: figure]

Рисунок 5.15 – Страница настроек оповещений в web-интерфейсе

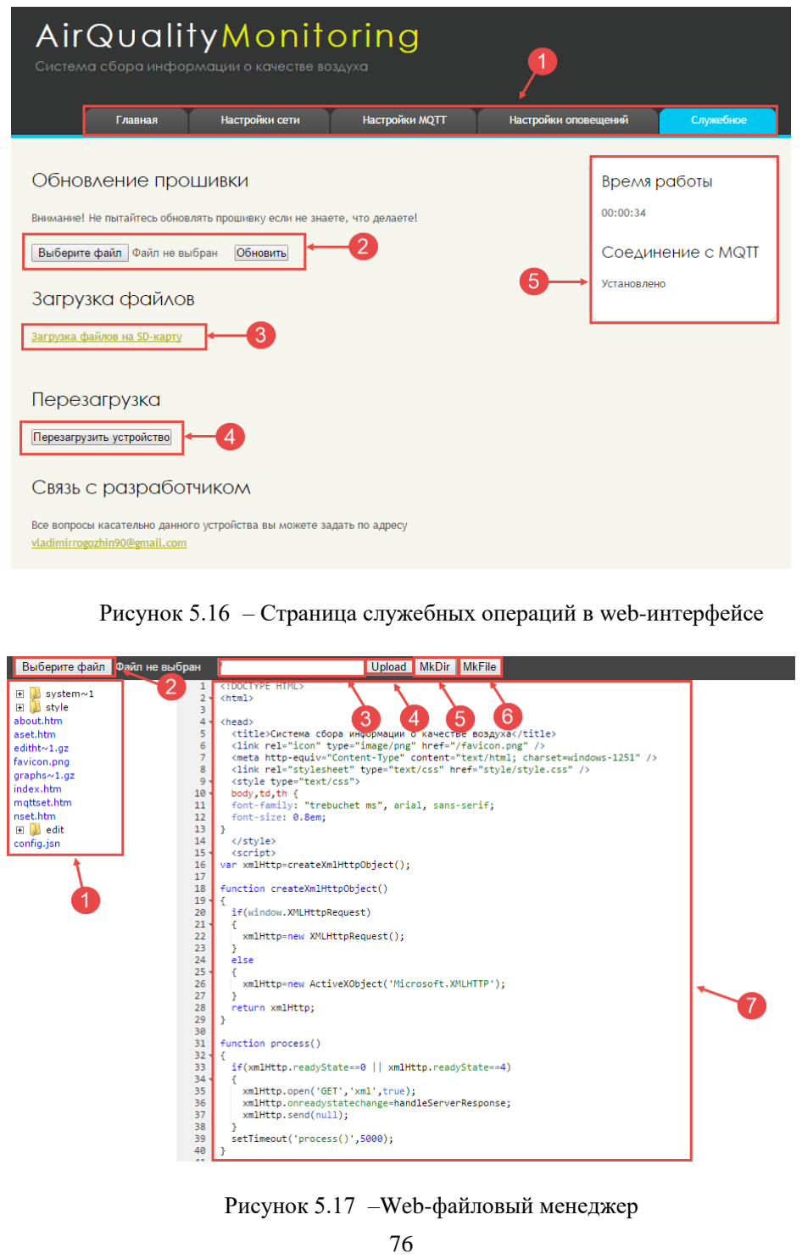
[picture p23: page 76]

Рисунок 5.16 – Страница служебных операций в web-интерфейсе

Рисунок 5.17 –Web-файловый менеджер

БЕЗОПАСНОСТЬ ЖИЗНЕДЕЯТЕЛЬНОСТИ

### 6.1 Введение

### 6.1.1 Цель дипломного проекта

Целью | дипломного | проекта | является | разработка | аппаратно-

программного комплекса для мониторинга качества воздуха в жилых

помещениях. В ходе работы был собран макет устройства, написано

программное обеспечение для микроконтроллеров, входящих в состав

устройства.

### 6.1.2 Характеристика рабочего места

Рабочее место располагается в комнате офисного помещения,

находящегося в жилом доме (дом проекта 141СВ-014), оборудованном под

рабочий кабинет. Рабочее место в помещении единственное. Помещение

имеет площадь 16 м2, высота потолка 2,75 м, общий объём помещения 44 м3,

располагается в Чкаловском районе города Екатеринбург. Климат в г.

Екатеринбург умеренно континентальный, с холодной зимой и тёплым летом.

Среднегодовая температура — +3.5 °C с тенденцией к быстрому увеличению.

Среднегодовое количество осадков — 537 мм [75], роза ветров приведена на

рисунке 6.1. В помещении расположено одно рабочее место. Рабочее место

оборудовано ПК. В состав ПК входят: системный блок типоразмера midi-

tower, ЖК монитор с диагональю 23 дюйма, акустическая система. При

необходимости рабочее место дооборудуется паяльной станцией Likei 936.

Рисунок 6.1 – Роза ветров

### 6.2 Безопасность проекта

### 6.2.1 Состояние воздуха рабочей зоны

### 6.2.1.1 Микроклимат

Параметры микроклимата в помещениях регламентируются ГОСТом

30494-2011 «Здания жилые и общественные. Параметры микроклимата в

помещениях» | [15]. | Под | микроклиматом | подразумевается | состояние

внутренней среды помещения, оказывающее воздействие на человека,

характеризуемое показателями температуры воздуха и ограждающих

конструкций, влажностью и подвижностью воздуха.

Параметры, характеризующие микроклимат:

- температура воздуха;
- скорость движения воздуха;
- относительная влажность воздуха;
- результирующая температура помещения;
- локальная асимметрия результирующей температуры.

Оптимальные и допустимые нормы температуры, относительной

влажности и скорости движения воздуха в обслуживаемой зоне помещений

жилых зданий и общежитий приведены в таблице 6.1.

Таблица 6.1 – Нормы температуры согласно [15]

Период года | Температура воздуха, °С | Результирующая температура, °С | Относительная влажность, % | Скорость движения воздуха, м/с
опти-маль-ная | допус-тимая | опти-маль-ная | допус-тимая | опти-мальная | допус-тимая не более | опти-мальная не более | допус-тимая не более
Холодный | 20-22 | 18-24 | 19-20 | 17-23 (19-23) | 45-30 | 60 | 0,15 | 0,2
Теплый | 22-25 | 20-28 | 22-24 | 18-27 | 60-30 | 65 | 0,2 | 0,3

Согласно ГОСТу [15] теплым называется период года с температурой

выше +8°С, холодным - с температурой ниже или равной +8°С.

С помощью разрабатываемого в ходе данной работы устройства были

замерены показатели температуры и влажности рабочего помещения, которые

составили 27,3 °С и 21% соответственно (при использовании увлажнителя

воздуха, влажность поднимается до 27%). Полученные показатели

температуры укладываются в допустимый интервал для тёплого сезона,

показатели влажности находятся ниже оптимальных.

Оборудование для замера результирующей температуры и скорости

движение воздуха отсутствует.

### 6.2.1.2 Качество воздуха

Параметры качества воздуха в помещениях регламентируются тем же

ГОСТом 30494-2011 «Здания жилые и общественные». Параметры

микроклимата в помещениях [15]. Под качеством воздуха подразумевается

состав воздуха в помещении, при котором при длительном воздействии на

человека обеспечивается оптимальное или допустимое состояние организма

человека.

Качество воздуха в помещениях жилых и общественных зданий

обеспечивается согласно действующим нормативно-техническим документам

[76] необходимым уровнем вентиляции (величиной воздухообмена в
помещениях), | обеспечивающим | допустимые | значения | содержания

углекислого газа в помещении. Классификация качества воздуха в

помещениях в зависимости от концентрации CO2 приведена в таблице 6.2.

Средние уровни содержания CO2 в воздухе приведены в таблице 6.3 [15].

Так же с помощью разрабатываемого устройства, были измерены

уровни CO2 как за пределами здания, так и в помещении. Средний уровень CO2 на улице составил 415 см³

| /м³

, 655 см³

/м³ в помещении, что позволяет

охарактеризовать качество воздуха в помещении как оптимальное (высокое).

Таблица 6.2 – Классы качества воздуха в зависимости от содержания

CO2

Класс | Качество воздуха в помещении | Допустимое содержание CO2*, см³ /м³
Оптимальное | Допустимое
1 | Высокое | - | 400 и менее
2 | Среднее | - | 400-600
3 | - | Допустимое | 600-1000
4 | - | Низкое | 1000 и более

* Допустимое содержание CO2 в помещениях принимают сверх содержания CO2 в наружном воздухе, см³

/м³
Таблица 6.3 – Средняя концентрация CO2 и CO в воздухе
Местность | Концентрация в воздухе
| CO2, см³ /м³ | CO, мг/м³
Сельская местность, существенные источники отсутствуют | 350 | 1
Небольшой город | 375 | 1-3
Загрязненный центр большого города | 400 | 2-6

### 6.2.1.3 Запыленность и загазованность воздуха рабочей зоны

Предельно допустимые концентрации вредных веществ в воздухе

рабочей зоны регламентируется гигиеническими нормативами ГН 2.2.5.1313-

03 [77], в воздухе населённых мест гигиеническими нормами ГН 2.1.6.1338-03

[18].

Из-за отсутствия датчиков, нет возможности произвести замеры

содержания вредных веществ воздухе, за исключением концентрации

взвешенных частиц в воздухе, а также содержания в воздухе оксида углерода

(угарного газа).

Гигиенические нормы ГН 2.2.5.1313-03 не регламентируют ПДК

взвешенных | частиц | неизвестного | происхождения, | поэтому | будем

использовать ПКД установленные в ГН 2.1.6.1338-03. Документом [18] устанавливается максимальная разовая концентрация равная 0,5 мг/м³
| | | | | ,
максимальная среднесуточная концентрация равная 0,15 мг/м³
| | | | [18].

Гигиенические нормы устанавливают [18] ПДК угарного газа в воздухе рабочей зоны на уровне 20 мг/м³
, что равно 17.2 ppm (частям на миллион).

По результатам измерений было установлено, что средняя концентрация

взвешенных части в рассматриваемом помещении находится на уровне 0,09 мг/м³

, а концентрация угарного газа на уровне 0,5 ppm или 0,58 мг/м³
, что

полностью соответствует гигиеническим нормам.

### 6.2.2 Освещённость

### 6.2.2.1 Требования к освещению рабочего места в зависимости от

разряда зрительной работы

Недостаток освещения рабочего места приводит к напряжению зрения,

понижается | общая | работоспособность | и | производительность | труда,

вследствие чего возрастает и количество ошибок. Чрезмерно яркое освещение

вызывает ослепление, раздражение и резь в глазах.

Нормативные требования к освещению рабочих мест с компьютерами

определяются несколькими документами – СНиП 23-05-95 «Естественное и

искусственное освещение» [78], СанПиН 2.2.1/2.1.1.1278-03 «Гигиенические

требования к естественному, искусственному и совмещенному освещению

жилых и общественных зданий» [79] и СанПиН 2.2.2/2.4.1340-03

«Гигиенические требования к персональным электронно-вычислительным

машинам и организации работы» [80]. Так же требования к освещению на

рабочем месте регламентируются ГОСТ Р... – (EН12464-1:2011) [81].

В помещении находится единственное окно, ориентированное на

восток. Так как в ходе данной работы производился монтаж элементов на

печатную плату, а размер выводов компонентов более 0,4 мм, можно

заключить, что согласно [78],, разряд зрительной работы Б-2. Нормируемое

значения КЕО eN, согласно [78], должен быть больше 0,7% (для бокового

освещения).

### 6.2.2.2 Расчет коэффициента естественной освещенности рабочего

места

Согласно | СНиП | 23-05-95/05 | [78] | нормируется | коэффициент

естественной освещенности. Расчет площади световых проемов производится

по формуле:

1 | 2
0
0

100

n n

S E K g K S
TV
- | · | · ·
=
| ··

(6.1)

где
n

S - площадь зала помещения (16 м
2
);

E
n - нормативное значение КЕО (0,7);

K1 - коэффициент запаса (1,4);

g - световая характеристика окон (43);

K2 - коэффициент, учитывающий затемнение окон противостоящими

зданиями (1);

V - коэффициент, учитывающий повышение КЕО, благодаря

отражению света (2);

T0 - общий коэффициент светопропускания, определяемый по

формуле (6.2).

T | T T T T 0 | 1 | 2 | 3 | 4
= | · | · ·
(6.2)

где

T1 - коэффициент светопропускания материала (для окон двойного

стекла 0,8);

T2 - потери света в переплетах светопроема (0,7);

T3 - потери света в несущих конструкциях (1);

83 T1 | - | потери | света | в | солнцезащитных | устройствах | (1)

K2 - коэффициент, учитывающий затемнение окон противостоящими

зданиями (1);

V - коэффициент, учитывающий повышение КЕО, благодаря

отражению света (2);

T0 - общий коэффициент светопропускания.

Таким образом, получаем:

S0 =

16 ∗ 0,7 ∗ 1,4 ∗ 43 ∗ 1
0.8 ∗ 0.7 ∗ 1 ∗ 1 ∗ 2 ∗ 100 =

647,24
112 = 5.77 м

2

Площадь оконного проема равна 1,38 м

2
, что недостаточно для работы

при естественном освещении, поэтому необходимо дополнительно применять

искусственное освещение.

### 6.2.2.3 Расчёт искусственного освещения

Для обозначения параметров рабочего места ГОСТ Р... – (EН12464-

1:2011) [81] вводятся следующие понятия:

- зрительная задача (visual task): Объект зрительной работы с

основными характеристиками, его определяющими (размер

объекта различения, его яркость, контраст с фоном и

продолжительность работы);

- зона зрительной задачи (task area): Часть площади рабочей

поверхности, на которой выполняется зрительная работа. Для

случаев, когда размер и/или расположение зрительной задачи

неизвестны, зона зрительной задачи, считается полной зоной

зрительной задачи.

- зона непосредственного окружения (immediate surrounding area):

Зона, шириной не менее 0,5м, окружающая объект наблюдения

внутри поля зрения;

- зона периферии (background area): Зона, следующая за зоной

непосредственного окружения объекта наблюдения;

- экраны мониторов (display screen equipment): Электронные экраны
- для отображения буквенно-цифровой информации, используемые

в процессе работы (90/270/ЕЕС);

- коэффициент пульсации освещенности K п , %: критерий оценки

относительной глубины колебаний освещенности в результате

изменения во времени светового потока источников света во

осветительной установке при питании их переменным током,

выражающийся формулой Kп = ((Емакс — Емин ) / 2 Еср) * 100 где E

макс и E мин - соответственно максимальное и минимальное

значения освещенности за период ее колебания, лк; E ср – среднее

значение освещенности за этот же период, лк.

На рабочих местах, где люди находятся постоянно, освещенность

должна быть не ниже 200лк. Для различных зон регламентируются различные

уровни освещенности.

Предполагается, что в области зрительной деятельности, внутри поля

зрения выделяются три зоны (рисунок 6.2):

1. зона зрительной задачи;
2. зона непосредственного окружения (полоса шириной не менее 0,5м,

окружающая зону зрительной задачи);

3. зона периферии (полоса шириной не менее 3м в пределах помещения,

следующая за зоной непосредственного окружения.

Освещенность в зоне непосредственного окружения связана с

освещенностью зрительной задачи и обеспечивает хорошо сбалансированное

распределение яркости в поле зрения.

Освещенность в зоне непосредственного окружения ниже, чем

освещенность зрительной задачи, но не должна быть меньше указанной в

таблице 4.

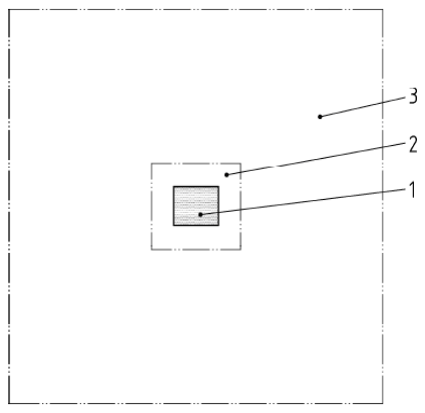
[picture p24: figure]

Рисунок 6.2 – Разделение поля зрения на зоны

Таблица 6.4 – Минимальные требования к освещённости зоны

зрительной задачи и зоны непосредственного окружения

Освещенность зрительной задачи,

лк

Освещенность зоны

непосредственного окружения, лк

Не менее 750
500
300
200
150
100
Не более 50

500
300
200
150
Е зр.задачи
Е зр.задачи
Е зр.задачи

Освещенность в зоне периферии также является эксплуатационной

освещенностью и не должна быть менее 1/3 от освещенности зоны

непосредственного окружения. Зона зрительной задачи должна быть освещена

как можно более равномерно.

Нормируемые показатели согласно [81] приведены в таблице 6.5. Так

как тип зрительной задачи различен, будем ориентироваться на более высокие

требования.

Таблица 6.5 – Требования к параметрам освещённости рабочего места

Наименование помещения, зрительной задачи и вида деятельности | Е экспл ,лк | Ra | K п , %
Электротехническая промышленность: монтажные операции высокой точности | 750 | 80 | 10
Офисы: письмо, машинопись, чтение, об-работка данных | 500 | 80 | 10

Освещение рабочих мест, оборудованных мониторами, должно

соответствовать требованию по отраженному свету (таблица 6.6).

Таблица 6.6 – Требования, предъявляемые к количеству отраженного

света от экранов мониторов

Процедура замера уровня освещенности достаточно подробно

рассмотрена в стандарте [81]. Предусматривается выбор сетки точек

измерений с отношением сторон в диапазоне от 0,5 до 2,0.

Максимальное расстояние между точками расчета внутри площадки

определяется по формуле:

Р=0,2х5lgd | (6.3)

где d — размер наибольшей стороны сетки в м при отношении длины

к ширине <2.

В соответствии с данной формулой и общими рекомендациями

стандарта было выбрано расстояние 30 см. Измерения проводились цифровым

датчиком освещенности на базе сенсора BH1750 соединённым посредством

макетной платы Arduino Uno с ПК. Результаты измерений приведены в

таблице 6.7.

Таблица 6.7 – Результаты измерений освещённости

Зона | Е ,лк
Экран монитора | 820, 930, 560
Зона зрительной задачи | 1110
Зона непосредственного окружения | 515, 650, 470, 550, 790, 550, 510, 480
Зона периферии | 330, 341, 259, 279, 294, 325, 346, 275, 234
Результаты измерений позволяют сделать вывод о соответствии

рабочего места по параметрам освещённости требованиям, предъявляемым к

рабочим местам для выполнения монтажных операций. Информация на мониторе представляется в позитивно, яркость монитора составляет 160 кд/м² ,

следовательно, яркость отраженного от монитора света находится в

допустимых пределах. Средняя освещённость зоны периферии составляет 0,58

от средней освещённости зоны непосредственного окружения, что так же

соответствует требованиям стандарта.

Дополнительно стандартом [81] регламентируются требования к

цветовой температуре и индексу цветопередачи используемых ламп.

Выполняемая работа подпадает под категорию «различение цветных объектов

при невысоких требованиях к цветоразличению, качество цветопередачи

отличное». Данная категория допускает использование ламп с цветовой

температурой порядка 2700К только при освещённости менее 300 лк, при

освещённости более 500 лк цветовая температура ламп должна находится в диапазоне от 4000К до 6000К. Индекс цветопередачи должен находится в

диапазоне от 80 до 84.

Источниками | искусственного | света | в | помещении | являются

светодиодные лампы IKEA 703.059.79 LED1476G22 (в потолочном

светильнике) и IKEA RYET 703.115.98 LED 1461G13 (в настольном

светильнике). Информация о параметрах используемых ламп, по данным

интернет-портала ламптест [82], приведена в таблице 6.8.

Таблица 6.8 – Параметры используемых ламп

Лампа | Световой поток ,лм | Цветовая температура, К | Индекс цветопередач и (Ra) | K п , %
LED 1476G22 | 1601 | 2727 | 92,5 | 10
LED 1461G13 | 1105 | 2754 | 83,2 | 13
Цветовая температура ламп не соответствует требованиям стандарта,

индекс цветопередачи лампы LED 1476G22 не соответствует требованиям

стандарта, но коэффициент пульсации находится в допустимых границах.

Лампа LED 1461G13 наоборот соответствует требованиям по индексу

цветопередачи, но не соответствует по коэффициенту пульсации.
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

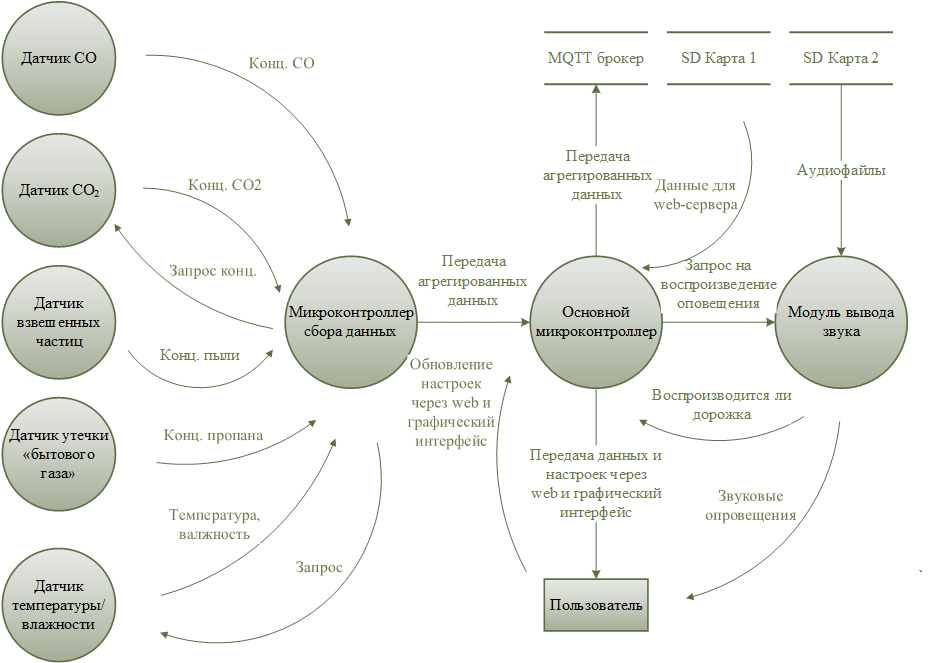
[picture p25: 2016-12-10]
Images/DFD.png

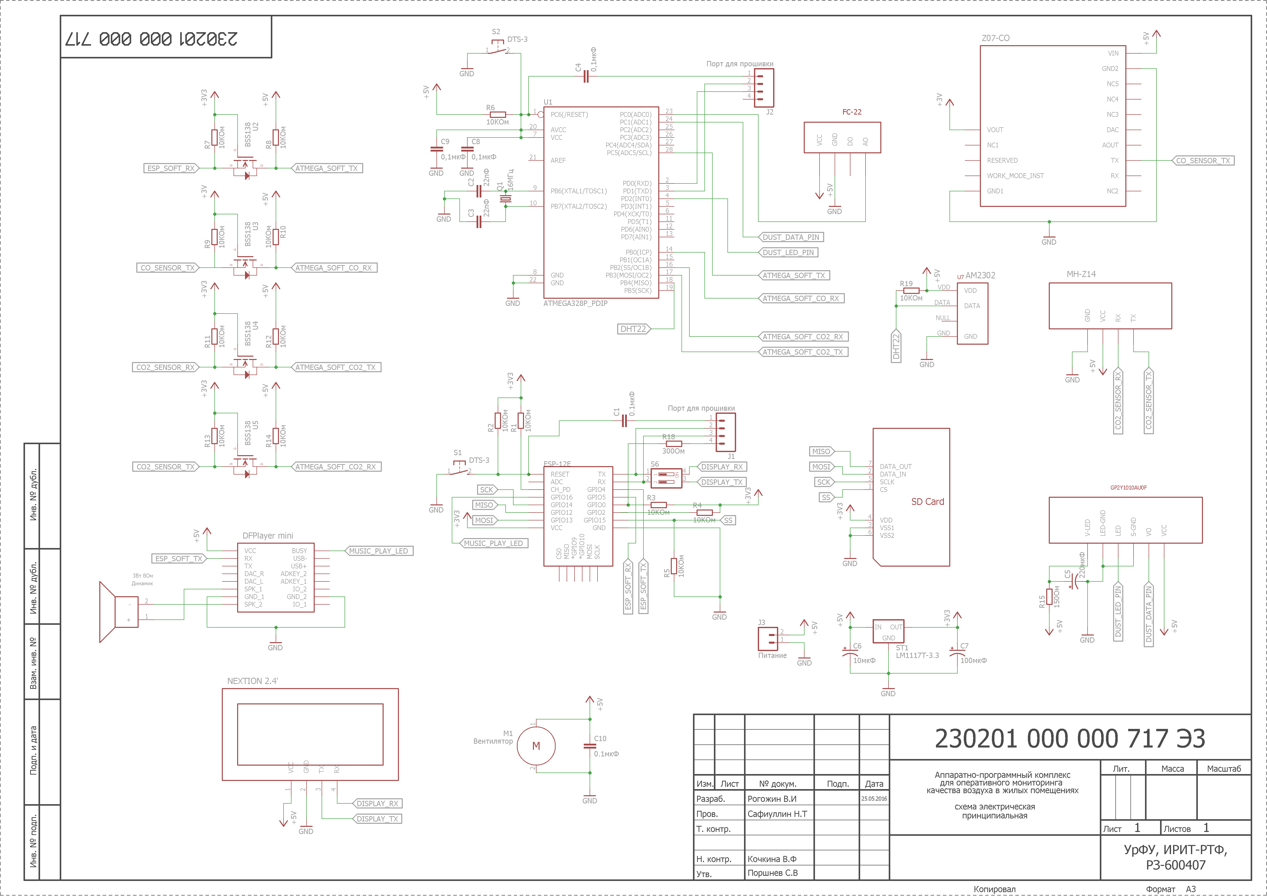
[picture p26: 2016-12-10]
Images/схема.png

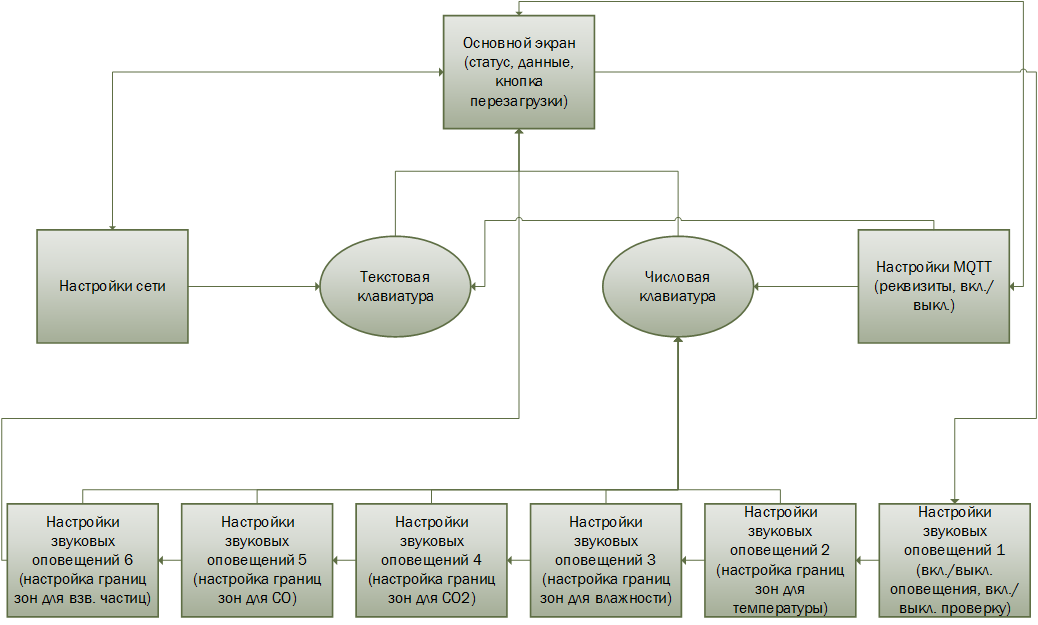
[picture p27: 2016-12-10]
Images/Интерфейс.png

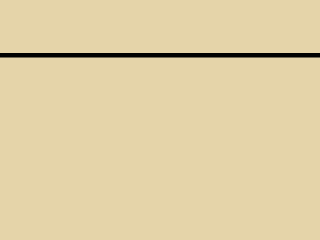
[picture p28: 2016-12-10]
Nextion/fon.png

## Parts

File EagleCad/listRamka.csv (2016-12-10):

Кол-во | Кол-во (100 устройств) | Value | Цена (1 устройство) | Стоимость (1 устр) | Цена (100 устройств) | Стоимость (100 устройств)
2 | 200 | DIP переключатель (1 контакт) | 1: 38.80 120: 31.04 240: 28.45
1 |  | DIP переключатель (2 контакта) | 1: 40.62 72: 32.50 216: 29.79
1 |  | Микроконтроллер ESP-12E | 121
1 |  | Датчик MQ-4 в составе модуля FC-22 | 86
1 |  | Датчик взвешенных частиц GP2Y1010AU0F | 260
3 |  | Конденцатор керамический 0,1мкФ | 1: 2.26 1000: 1.05 2000: 0.83
1 |  | Конденсатор электролитический полярный 100мкФ | 8 от 400 шт. — 5 от 4000 шт. — 3.50
16 |  | Резистор 10КОм (MFR-12JT-52- 10K) | 1: 1.42 1000: 0.53 5000: 0.39
1 |  | Конденсатор электролитический полярный 10мкФ | 5 от 400 шт. — 4 от 4000 шт. — 1.80
1 |  | Резистор 150Ом (MFR-12FTF52- 150R) | 1: 0.64 1000: 0.39 5000: 0.25
1 |  | Кварцевый резонатор 16МГц (hc-49u) | 15 от 300 шт. — 10 от 3000 шт. — 7.50
1 |  | Конденсатор электролитический полярный 220мкФ | 8 от 400 шт. — 5 от 4000 шт. — 3.20
2 |  | Конденцатор керамический 22пФ | 1: 1.88 1000: 0.88 2000: 0.69
1 |  | Микроконтроллер ATMEGA328P в DIP корпусе | 1: 150.15 14: 135.14 70: 127.05
5 |  | MOSFET транзистр BSS138 (SOT23-3) | 1: 3.16 500: 1.98 3000: 1.74
1 |  | Модуль DfPlayer mini | 207
2 |  | Тактовая кнопка DTS-3 | от 1 шт: 7.18 руб. от 135 шт: 5.75 руб. от 675 шт: 4.79 руб.
1 |  | Линейный стабилизатор LM1117T-3.3 | от 1 шт: 65.43 руб. от 15 шт: 52.35 руб. от 45 шт: 47.98 руб.
1 |  | Датчик углекислого газа MH-Z14 | 1830
1 |  | Дисплей NEXTION 2.8' | 852
1 |  | Вилка на плату PLS-40 | 1: 8.93 200: 5.58 400: 4.91
2 |  | Micro Sd Card | 116
1 |  | Динамик 3Вт, 8 Ом | 1: 193.21 10: 173.89 20: 163.48
1 |  | Датчик угарного газа ZE07-CO | 1250
1 |  | Блок питания 5В, 2А | 140
1 |  | Корпус
1 |  | Гнездо питания на панель DJK-04A | 100 от 100 шт. — 85 руб.
2 |  | Гнездо на плату 2мм 1х10 прямое PBS2-10 | 55 от 400 шт. — 40 руб. от 2000 шт. — 8.32 руб. (3 дня)
3 |  | Гнездо на кабель BLS-1x04 | 1: 3.73 100: 2.49 500: 1.66
1 |  | Гнездо на кабель BLS-1x06 | 1: 4.37 100: 2.91 500: 1.94

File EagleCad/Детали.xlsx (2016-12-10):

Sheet: listRamka
Кол-во | Кол-во (100 устройств) | Позиция | Цена (1 устройство) | Стоимость (1 устр) | Цена (100 устройств) | Стоимость (100 устройств) | Транспортно-заготовительный1 расходы, руб. | Сумма затрат на позицию
1 | 100 | DIP переключатель (2 контакта) | 40.62 | 40.62 | 32.5 | 3250 | 0.8124 | 41.4324
1 | 100 | Датчик AM2303 | 175 | 175 | 175 | 17500 | 3.5 | 178.5
1 | 100 | Микроконтроллер ESP-12E | 121 | 121 | 121 | 12100 | 2.42 | 123.42
1 | 100 | Датчик MQ-4 в составе модуля FC-22 | 86 | 86 | 86 | 8600 | 1.72 | 87.72
1 | 100 | Датчик взвешенных частиц GP2Y1010AU0F | 260 | 260 | 260 | 26000 | 5.2 | 265.2
4 | 400 | Конденцатор керамический 0,1мкФ | 2.26 | 9.04 | 2.26 | 904 | 0.1808 | 9.2208
1 | 100 | Конденсатор электролитический полярный 100мкФ | 8 | 8 | 8 | 800 | 0.16 | 8.16
17 | 1700 | Резистор 10КОм (MFR-12JT-52- 10K) | 1.42 | 24.14 | 0.53 | 901 | 0.4828 | 24.6228
1 | 100 | Конденсатор электролитический полярный 10мкФ | 5 | 5 | 5 | 500 | 0.1 | 5.1
1 | 100 | Резистор 300Ом (MFR-12JT-52- 300R) | 1.42 | 1.42 | 1.42 | 142 | 0.0284 | 1.4484
1 | 100 | Резистор 150Ом (MFR-12FTF52- 150R) | 0.64 | 0.64 | 0.64 | 64 | 0.0128 | 0.6528
1 | 100 | Кварцевый резонатор 16МГц (hc-49u) | 15 | 15 | 15 | 1500 | 0.3 | 15.3
1 | 100 | Конденсатор электролитический полярный 220мкФ | 8 | 8 | 8 | 800 | 0.16 | 8.16
2 | 200 | Конденцатор керамический 22пФ | 1.88 | 3.76 | 1.88 | 376 | 0.0752 | 3.8352
1 | 100 | Микроконтроллер ATMEGA328P в DIP корпусе | 150.15 | 150.15 | 135.14 | 13514 | 3.003 | 153.153
5 | 500 | MOSFET транзистр BSS138 (SOT23-3) | 3.16 | 15.8 | 1.98 | 990 | 0.316 | 16.116
1 | 100 | Модуль DfPlayer mini | 207 | 207 | 207 | 20700 | 4.14 | 211.14
2 | 200 | Тактовая кнопка DTS-3 | 7.18 | 14.36 | 5.75 | 1150 | 0.2872 | 14.6472
1 | 100 | Линейный стабилизатор LM1117T-3.3 | 65.43 | 65.43 | 52.35 | 5235 | 1.3086 | 66.7386
1 | 100 | Датчик углекислого газа MH-Z14 | 1830 | 1830 | 1830 | 183000 | 36.6 | 1866.6
1 | 100 | Дисплей NEXTION 2.8' | 852 | 852 | 852 | 85200 | 17.04 | 869.04
1 | 100 | Вилка на плату PLS-40 | 8.93 | 8.93 | 8.93 | 893 | 0.1786 | 9.1086
2 | 200 | MicroSD карта | 116 | 232 | 116 | 23200 | 4.64 | 236.64
1 | 100 | Динамик 3Вт, 8 Ом | 193.71 | 193.71 | 173.89 | 17389 | 3.8742 | 197.5842
1 | 100 | Датчик угарного газа ZE07-CO | 1250 | 1250 | 1250 | 125000 | 25 | 1275
1 | 100 | Блок питания 5В, 2А | 140 | 140 | 140 | 14000 | 2.8 | 142.8
1 | 100 | Корпус | 500 | 500 | 500 | 50000 | 10 | 510
1 | 100 | Гнездо питания на панель DJK-04A | 100 | 100 | 85 | 8500 | 2 | 102
2 | 200 | Гнездо на плату 2мм 1х10 прямое PBS2-10 | 55 | 110 | 55 | 11000 | 2.2 | 112.2
3 | 300 | Гнездо на кабель BLS-1x04 | 3.73 | 11.19 | 2.49 | 747 | 0.2238 | 11.4138
1 | 100 | Гнездо на кабель BLS-1x06 | 4.37 | 4.37 | 2.91 | 291 | 0.0874 | 4.4574
1 | 100 | Текстолит | 120 | 120 |  |  | 2.4 | 122.4
 |  |  | Сумма: | 6562.56 | Сумма | 634246 | Сумма (НИР) | 6693.8112
 |  |  |  |  | На 1 устройство: | 6342.46
 |  |  |  |  |  |  |  | 56 за плату

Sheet: Лист1
Позиция | Колличество, шт. | Цена, руб./шт. | Стоимость, руб.
Отладочная плата WeMos D1 | 1 | 365.01 | 365.01
Отладочная плата Arduino UNO | 1 | 331.08 | 331.08
Отладочная плата (без пайки) | 2 | 164.2 | 328.4
Набор проводов для отладочной платы | 2 | 88.17 | 176.34
Модуль конвертера уровней | 2 | 49.76 | 99.52
USB-UART переходник | 1 | 48.85 | 48.85
Итого |  |  | 1349.2

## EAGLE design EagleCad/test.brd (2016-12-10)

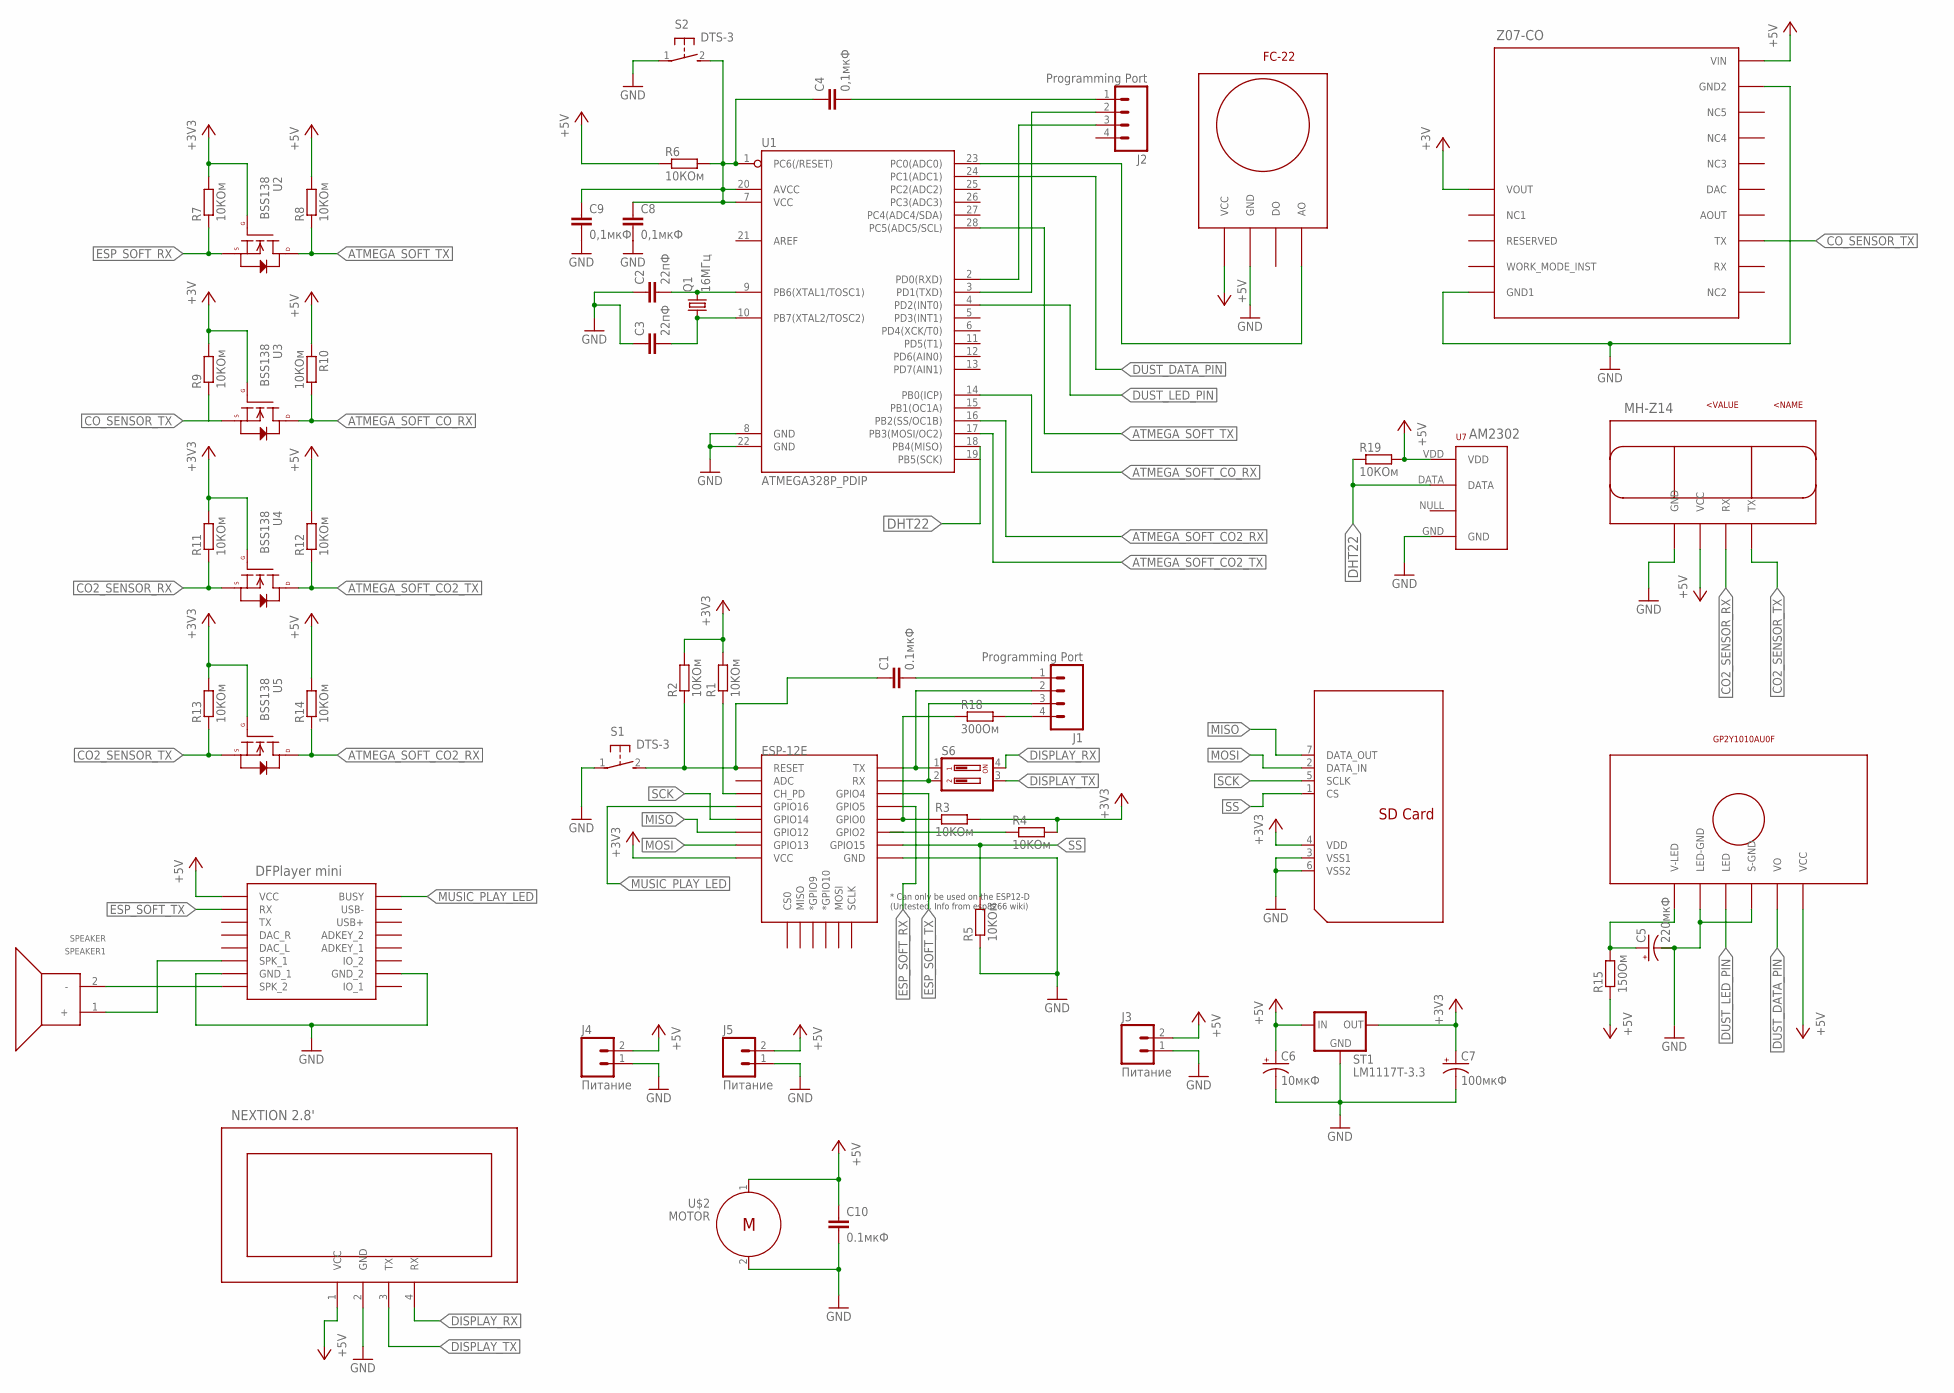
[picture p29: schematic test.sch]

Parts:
C1, C10: 0.1мкФ; CAP-PTH-SMALL-KIT
C2, C3: 22пФ; CAP-PTH-SMALL-KIT
C4, C8, C9: 0,1мкФ; CAP-PTH-SMALL-KIT
C5: 220мкФ; CPOL-RADIAL-10UF-25V-KIT
C6: 10мкФ; CPOL-RADIAL-10UF-25V-KIT
C7: 100мкФ; CPOL-RADIAL-10UF-25V-KIT
ESP-12E: ESP12ESMD; ESP12E-SMD
FC-22: FC-22FC-22-STANDART; FC-22
GP2Y1010AU0F: GP2Y1010AU0FGP2Y1010AU0F; 1X06
J1, J2: Programming Port; 1X04
J3, J4, J5: Питание; 1X02
MH-Z14: MH-Z14; 1X04
NEXTION1: NEXTION; 1X04
Q1: 16МГц; HC49/S
R1, R2, R3, R4, R5: 10KОм; 0207/10
R6, R7, R8, R9, R10, R11, R12, R13, R14, R19: 10КОм; 0207/10
R15: 150Ом; 0207/10
R18: 300Ом; 0207/10
S1, S2: DTS-3
S6: DS02; DS-02
SDCARD-1: SDCARDSDSTAY; SD
SPEAKER1: SPEAKER; 1X02
ST1: LM1117T-3.3; 78XXL
U1: ATMEGA328P_PDIP; DIL28-3
U2, U3, U4, U5: BSS138; SOT23-3
U7: RHT03_DHT-22_AM2302; RHT03_DHT-22
U$1: DFPLAYER
U$2: MOTOR; 1X02
Z07-CO-1: ZE07-CO; Z07-CO

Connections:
+3V3: C7.1 (+), ESP-12E.VCC, R1.2, R2.2, R3.2, R4.2, R7.2, R11.2, R13.2, ST1.GND (OUT), U2.1 (G), U4.1 (G), U5.1 (G)
+5V: C6.1 (+), C10.1, FC-22.1 (VCC), GP2Y1010AU0F.6 (VCC), J3.2, J4.2, J5.2, MH-Z14.3 (VCC), NEXTION1.1 (VCC), R6.1, R8.2, R10.1, R12.2, R14.2, R15.1, R19.2, ST1.OUT (IN), U7.VDD, U$1.VCC, U$2.1, Z07-CO-1.15 (VIN)
ATMEGA_SOFT_CO2_RX: R14.1, U1.16 (PB2(SS/OC1B)), U5.3 (D)
ATMEGA_SOFT_CO2_TX: R12.1, U1.17 (PB3(MOSI/OC2)), U4.3 (D)
ATMEGA_SOFT_CO_RX: R10.2, U1.14 (PB0(ICP)), U3.3 (D)
ATMEGA_SOFT_TX: R8.1, U1.28 (PC5(ADC5/SCL)), U2.3 (D)
CO2_SENSOR_RX: MH-Z14.2 (RX), R11.1, U4.2 (S)
CO2_SENSOR_TX: MH-Z14.1 (TX), R13.1, U5.2 (S)
CO_SENSOR_TX: R9.1, U3.2 (S), Z07-CO-1.8 (TX)
DHT22: R19.1, U1.18 (PB4(MISO)), U7.DATA
DISPLAY_RX: NEXTION1.4 (RX), S6.4
DISPLAY_TX: NEXTION1.3 (TX), S6.3
DUST_DATA_PIN: GP2Y1010AU0F.5 (VO), U1.24 (PC1(ADC1))
DUST_LED_PIN: GP2Y1010AU0F.3 (LED), U1.4 (PD2(INT0))
ESP_SOFT_RX: ESP-12E.GPIO5, R7.1, U2.2 (S)
ESP_SOFT_TX: ESP-12E.GPIO4, U$1.RX
GND: C2.1, C3.1, C5.2 (-), C6.2 (-), C7.2 (-), C8.2, C9.2, C10.2, ESP-12E.GND, FC-22.2 (GND), GP2Y1010AU0F.2 (LED-GND), GP2Y1010AU0F.4 (S-GND), J3.1, J4.1, J5.1, MH-Z14.4 (GND), NEXTION1.2 (GND), R5.1, S1.1, S2.1, ST1.IN (GND), U1.8 (GND), U1.22 (GND), U7.GND, U$1.GND_1, U$1.GND_2, U$2.2, Z07-CO-1.5 (GND1), Z07-CO-1.14 (GND2)
MISO: ESP-12E.GPIO12, SDCARD-1.7 (DATA_OUT)
MOSI: ESP-12E.GPIO13, SDCARD-1.2 (DATA_IN)
MUSIC_PLAY_LED: ESP-12E.GPIO16, U$1.BUSY
unnamed: C5.1 (+), GP2Y1010AU0F.1 (V-LED), R15.2
unnamed: C4.1, C8.1, C9.1, R6.2, S2.2, U1.1 (PC6(/RESET)), U1.7 (VCC), U1.20 (AVCC)
unnamed: ESP-12E.CH_PD, R1.1
unnamed: ESP-12E.GPIO0, R3.1, R18.1
unnamed: ESP-12E.GPIO2, R4.1
unnamed: ESP-12E.RXD0 (RX), J1.3, S6.2
unnamed: C1.1, ESP-12E.RESET, R2.1, S1.2
unnamed: C1.2, J1.1
unnamed: ESP-12E.TXD0 (TX), J1.2, S6.1
unnamed: C3.2, Q1.1, U1.10 (PB7(XTAL2/TOSC2))
unnamed: SPEAKER1.1 (+), U$1.SPK1 (SPK_1)
unnamed: SPEAKER1.2 (-), U$1.SPK2 (SPK_2)
unnamed: C2.2, Q1.2, U1.9 (PB6(XTAL1/TOSC1))
unnamed: C4.2, J2.1
unnamed: J2.2, U1.3 (PD1(TXD))
unnamed: J1.4, R18.2
unnamed: J2.3, U1.2 (PD0(RXD))
unnamed: FC-22.4 (AO), U1.23 (PC0(ADC0))
SCK: ESP-12E.GPIO14, SDCARD-1.5 (SCLK)
SS: ESP-12E.GPIO15, R5.2, SDCARD-1.1 (CS)
VCC: R9.2, U3.1 (G), Z07-CO-1.1 (VOUT)
VDD: SDCARD-1.4 (VDD)
VSS2: SDCARD-1.3 (VSS1), SDCARD-1.6 (VSS2)

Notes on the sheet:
NEXTION 2.8'
DFPlayer mini
MH-Z14
Z07-CO
AM2302

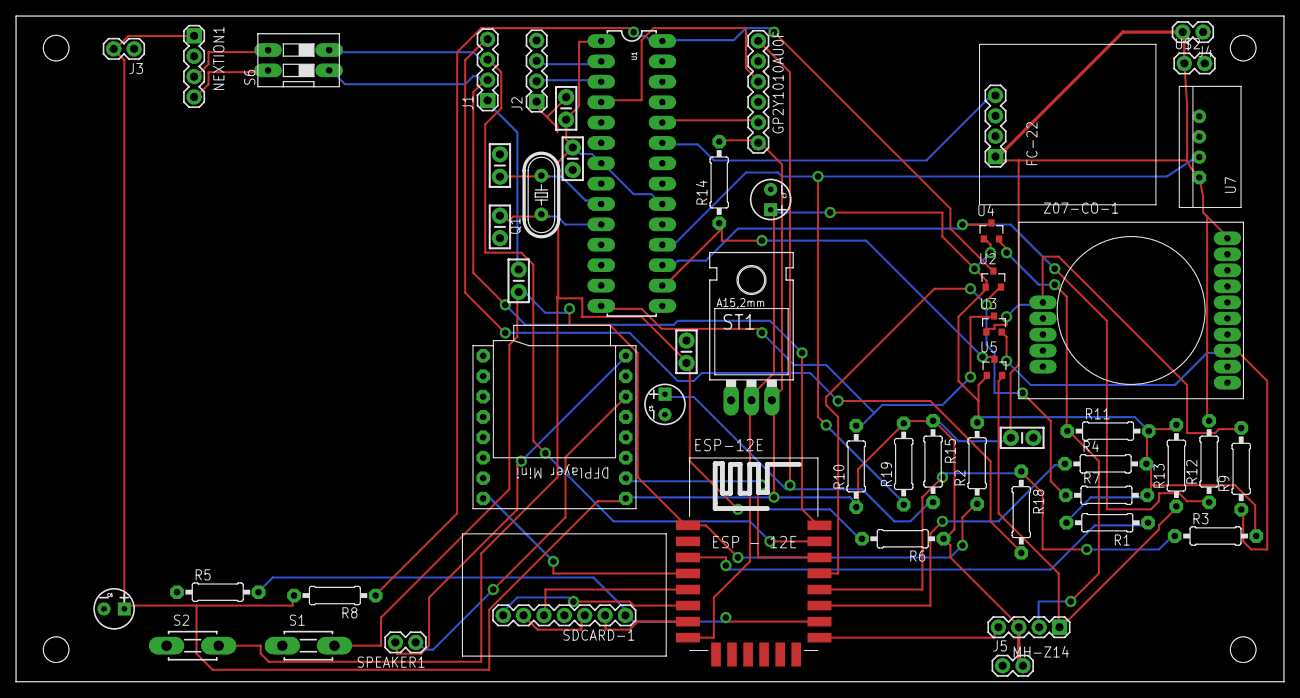
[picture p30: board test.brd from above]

Board: 2 copper layers, 158.1 x 83.0 mm, 53 parts (0 on the bottom side), 42 nets.

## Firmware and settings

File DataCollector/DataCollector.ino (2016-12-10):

#include "DHT.h"
#include <SoftwareSerial.h>
#include "RunningAverage.h"

#define UNSIGNED_LONG_MAX 4294967295UL

char DataString[90];

#pragma region Settings
struct SettingsStruct {
  unsigned long MicroclimatProgrev; //Время на прогрев датчика
  unsigned long MicroclimatInterval; //Интервал опроса датчика
  int MicroclimatSMAPoints; //Колличиство отсчётов в фильтре НЧ

  unsigned long CO2Progrev;
  unsigned long CO2Interval;
  int CO2SMAPoints;

  unsigned long COProgrev;
  int COSMAPoints;

  unsigned long DustProgrev;
  unsigned long DustInterval;
  int DustSMAPoints;

  unsigned long LPGProgrev;
  unsigned long LPGInterval;
  int LPGSMAPoints;

  unsigned int SendDataInterval;
} settings = {
  2000,
  2000,
  10,

  2000,
  2000,
  10,

  5000,
  10,

  1000,
  500,
  15,

  300000UL, // 5 минут
  200,
  10,

  1000
};

#pragma endregion

#pragma region Globals
#define DHTPIN 12
#define DHTTYPE DHT22 
DHT dht(DHTPIN, DHTTYPE);

SoftwareSerial SoftSerialCO2(10, 11); // RX, TX
SoftwareSerial SoftSerialCO(8, 9); // RX, TX
#pragma endregion


#pragma region Microclimat
unsigned long prev_micro = 0;

RunningAverage temperatureSMA(settings.MicroclimatSMAPoints);
RunningAverage humiditySMA(settings.MicroclimatSMAPoints);
void ProcessMicroclimat()
{
  float t = dht.readTemperature();
  float h = dht.readHumidity();

  if (!isnan(t)) temperatureSMA.addValue(t);
  if (!isnan(h)) humiditySMA.addValue(h);
}
#pragma endregion 
#pragma region CO2
unsigned long prev_co2 = 0;

RunningAverage CO2SMA(settings.CO2SMAPoints);
void ProcessCO2()
{
  SoftSerialCO2.listen();
  while (SoftSerialCO2.available()) SoftSerialCO2.read();
  const byte request[] = { 0xff, 0x01, 0x86, 0x00, 0x00, 0x00, 0x00, 0x00, 0x79 };
  byte result[9];
  byte checksum = 0;
  SoftSerialCO2.write(request,sizeof(request));
  while (!SoftSerialCO2.available()) {} 
  for (byte i = 0; i < 9; i++)
  {
    delay(5);
    result[i] = SoftSerialCO2.read();
    if ((i>0) && (i<8)) checksum += result[i];
  }
  checksum = (~checksum) + 1;
  
  if (checksum == result[8])
  {
    int temp = result[2] * 256 + result[3];
    CO2SMA.addValue(temp);
  }
  SoftSerialCO.listen();
}
#pragma endregion
#pragma region CO
volatile unsigned long COReciveTime = 0;
RunningAverage COSMA(settings.COSMAPoints);
bool COReciveFlag = false;
void COCallback()
{
	COReciveFlag = true;
	COReciveTime = millis();
}
void ProcessCO()
{
	byte result[9];
	while (!SoftSerialCO.available()) {}
	byte checksum = 0;
	for (byte i = 0; i < 9; i++)
	{
		delay(5);
		result[i] = SoftSerialCO.read();
		if ((i>0) && (i<8)) checksum += result[i];
	}
	checksum = (~checksum) + 1;

	if (checksum == result[8])
	{
		float temp = (result[4] * 256 + result[5])*0.1;
		COSMA.addValue(temp);
	}
}
#pragma endregion
#pragma region Dust
#define samplingTime 280
#define deltaTime 40

unsigned long prev_dust = 0;

RunningAverage DustSMA(settings.DustSMAPoints);

void ProcessDust()
{
  digitalWrite(2, LOW); // Подаём питание на LED
  delayMicroseconds(samplingTime);

  float voMeasured = analogRead(A1);

  delayMicroseconds(deltaTime);
  digitalWrite(2, HIGH); // Выключаем

  float calcVoltage = voMeasured * (5.0 / 1023.0);
  float dustDensity = 0.167255 * calcVoltage - 0.0921552;
  if(dustDensity>0) DustSMA.addValue(dustDensity);
  else DustSMA.addValue(0);
}
#pragma endregion
#pragma region LPG
unsigned long prev_lpg = 0;

float LPGCurve[2] = {13.91826722,-0.320860296};
float RL_VALUE = 1;
float Ro = 1.22;


RunningAverage LPGSMA(settings.LPGSMAPoints);

void ProcessLPG()
{
  if (!temperatureSMA.FullBuffer()) return; //Продолжаем только если у нас есть данные о микроклимате
  float voMeasured = analogRead(A0);

  float vcc = readVcc();
  float vrl = voMeasured*(vcc / 1023);
  float resistance = (vcc - vrl) / vrl*RL_VALUE;

  resistance = resistance*(1.147618596*pow(2.71828182846, ((-0.00550023923)*temperatureSMA.getFastAverage()))); //Компенсация температуры
  resistance = resistance + (33.0 - humiditySMA.getFastAverage())*0.002884615; //Компенсация влажности
  float ratio = resistance / Ro;
  
  float result = LPGCurve[0] * pow(ratio,LPGCurve[1]);

  LPGSMA.addValue(result);
}

float readVcc()  //this function actual only for ATMega328
{
  byte i;
  float result = 0.0;
  float tmp = 0.0;

  for (i = 0; i < 5; i++) 
  {
    ADMUX = _BV(REFS0) | _BV(MUX3) | _BV(MUX2) | _BV(MUX1);
 
    delay(3);
    ADCSRA |= _BV(ADSC);
    while (bit_is_set(ADCSRA,ADSC));

    uint8_t low  = ADCL;
    uint8_t high = ADCH;

    tmp = (high<<8) | low;
    tmp = (1.1 * 1023.0) / tmp;
    result = result + tmp;
    delay(5);
  }

  result = result / 5;
  return result;
}


#pragma endregion
#pragma region SoftTX
SoftwareSerial SoftTransmitter(A4, A5); // RX, TX
unsigned long send_prev = 0;

void MakeDataString()
{
  DataString[0] = '\0';
  char tempNum[6];
    if (temperatureSMA.FullBuffer()) //Микроклимат
    {
      dtostrf(temperatureSMA.getAverage(), 6, 2, tempNum);
      trim(tempNum);
      strcat(DataString, tempNum);
      strcat(DataString, ";");
      dtostrf(temperatureSMA.GetStandardError(), 6, 2, tempNum);
      trim(tempNum);
      strcat(DataString, tempNum);
      strcat(DataString, ";");
      dtostrf(humiditySMA.getAverage(), 6, 2, tempNum);
      trim(tempNum);
      strcat(DataString, tempNum);
      strcat(DataString, ";");
      dtostrf(humiditySMA.GetStandardError(), 6, 2, tempNum);
      trim(tempNum);
      strcat(DataString, tempNum);
      strcat(DataString, "|");
    }
    else
    {
      strcat(DataString, "-1;-1;-1;-1");
    }

    if (CO2SMA.FullBuffer()) //CO2
    {
      dtostrf(CO2SMA.getFastAverage(), 7, 2, tempNum);
      trim(tempNum);
      strcat(DataString, tempNum);
      strcat(DataString, ";");
      dtostrf(CO2SMA.GetStandardError(), 7, 2, tempNum);
      trim(tempNum);
      strcat(DataString, tempNum);
      strcat(DataString, "|");
    }
    else
    {
      strcat(DataString, "-1;-1|");
    }

    if (COSMA.FullBuffer()) //CO
    {
      dtostrf(COSMA.getFastAverage(), 6, 2, tempNum);
      trim(tempNum);
      strcat(DataString, tempNum);
      strcat(DataString, ";");
      dtostrf(COSMA.GetStandardError(), 6, 2, tempNum);
      trim(tempNum);
      strcat(DataString, tempNum);
      strcat(DataString, "|");
    }
    else
    {
      strcat(DataString, "-1;-1|");
    }

    if (DustSMA.FullBuffer()) //Пыль
    {
      dtostrf(DustSMA.getFastAverage(), 6, 2, tempNum);
      trim(tempNum);
      strcat(DataString, tempNum);
      strcat(DataString, ";");
      dtostrf(DustSMA.GetStandardError(), 6, 2, tempNum);
      trim(tempNum);
      strcat(DataString, tempNum);
      strcat(DataString, "|");
    }
    else
    {
      strcat(DataString, "-1;-1|");
    }

    if (LPGSMA.FullBuffer()) //Газ
    {
      dtostrf(LPGSMA.getFastAverage(), 6, 2, tempNum);
      trim(tempNum);
      strcat(DataString, tempNum);
      strcat(DataString, ";");
      dtostrf(LPGSMA.GetStandardError(), 6, 2, tempNum);
      trim(tempNum);
      strcat(DataString, tempNum);
    }
    else
    {
      strcat(DataString, "-1;-1");
    }
 
  byte CRC = 0;
  for (size_t i = 0; i < strlen(DataString);i++)
  {
    CRC = CRC + (byte)(*(DataString+i));
  }

  char str[4];
  sprintf(str, "%03d", CRC);
  
  strcat(DataString, "*");
  strcat(DataString, str);
}


void trim(char *str)
{
    int i;
    int begin = 0;
    int end = strlen(str) - 1;

    while (isspace(str[begin]))
    {
      begin++;
    }
    while ((end >= begin) && isspace(str[end]))
    {
      end--;
    }
    for (i = begin; i <= end; i++)
    {
      str[i - begin] = str[i];
    }
    str[i - begin] = '\0';
}

#pragma endregion

void setup() 
{
  Serial.begin(9600);

  SoftSerialCO2.begin(9600);
  delay(10);
  SoftSerialCO.begin(9600);
  delay(10);
  SoftTransmitter.begin(9600);

  SoftSerialCO.onReceiveAttach(COCallback);

  pinMode(2, OUTPUT);
}


unsigned long check_overflow=0;
bool overflow = false;
void loop() 
{
  if (check_overflow > millis()) overflow = true;
  #pragma region LOOP
  if (((!overflow) && (millis() > settings.MicroclimatProgrev) && (millis() - prev_micro >= settings.MicroclimatInterval))
    || ((overflow) && (UNSIGNED_LONG_MAX - check_overflow + millis() >= settings.MicroclimatInterval)))
  {
    ProcessMicroclimat();
    prev_micro = millis();
  }
  if (((!overflow) && (millis() > settings.CO2Progrev) && (millis() - prev_co2 >= settings.CO2Interval)) 
    || ((overflow) && (UNSIGNED_LONG_MAX - check_overflow + millis() >= settings.CO2Interval)))
  {
    ProcessCO2();
    prev_co2 = millis();
  }
  if ((millis() > settings.COProgrev) && COReciveFlag && ((millis() - COReciveTime) >= 20))
  {
    ProcessCO();
  }
  if (((!overflow) && (millis() > settings.DustProgrev) && (millis() - prev_dust >= settings.DustInterval))
    || ((overflow) && (UNSIGNED_LONG_MAX - check_overflow + millis() >= settings.DustInterval)))
  {
    ProcessDust();
    prev_dust = millis();
  }
  if (((!overflow) && (millis() > settings.LPGProgrev) && (millis() - prev_lpg >= settings.LPGInterval))
    || ((overflow) && (UNSIGNED_LONG_MAX - check_overflow + millis() >= settings.LPGInterval)))
  {
    ProcessLPG();
    prev_lpg = millis();
  }


  if (((!overflow) && (millis() - send_prev >= settings.SendDataInterval))
    || ((overflow) && (UNSIGNED_LONG_MAX - check_overflow + millis() >= settings.SendDataInterval)))
  {
    MakeDataString();
    SoftTransmitter.println(DataString);
    
    send_prev = millis();
  }
  #pragma endregion
  check_overflow = millis();
  overflow = false;
}

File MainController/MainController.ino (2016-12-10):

#include <NextionWaveform.h>
#include <NextionVariableString.h>
#include <NextionVariableNumeric.h>
#include <NextionTypes.h>
#include <NextionTimer.h>
#include <NextionText.h>
#include <NextionSlider.h>
#include <NextionProgressBar.h>
#include <NextionPicture.h>
#include <NextionPage.h>
#include <NextionNumber.h>
#include <NextionHotspot.h>
#include <NextionGauge.h>
#include <NextionDualStateButton.h>
#include <NextionCrop.h>
#include <NextionCallbackFunctionHandler.h>
#include <NextionButton.h>
#include <Nextion.h>
#include <INextionWidget.h>
#include <INextionTouchable.h>
#include <INextionStringValued.h>
#include <INextionNumericalValued.h>
#include <INextionFontStyleable.h>
#include <INextionColourable.h>
#include <INextionCallback.h>
#include <ArduinoJson.h>
#include <DFPlayer_Mini_Mp3.h>
#include <LinkedList.h>
#include <SoftwareSerial.h>
#include <Wire.h>
#include <SD.h>
#include <ESP8266WiFi.h>
#include <ESP8266WebServer.h>
#include <SPI.h>
#include "WiFiUdp.h"
#include <PubSubClient.h>
#include "Diplom.h"

#define UNSIGNED_LONG_MAX 4294967295UL

#pragma region Global
bool hasSD = false;

const int sclPin = D3; //Пины I2C
const int sdaPin = D4;

#define PERIOD_ZAPROSA_DANNYH 1000UL;
unsigned long prev_zapros = 0;

ESP8266WebServer HTTP(80);
File fsUploadFile;

WiFiClient espClient;
PubSubClient MQTTClient(espClient);

struct Data {
	float temperature;
	float temperature_Error;
	float humidity;
	float humidity_Error;
	float CO2;
	float CO2_Error;
	float CO;
	float CO_Error;
	float dust;
	float dust_Error;
	float LPG;
	float LPG_Error;

	String temperature_S;
	String temperature_Error_S;
	String humidity_S;
	String humidity_Error_S;
	String CO2_S;
	String CO2_Error_S;
	String CO_S;
	String CO_Error_S;
	String dust_S;
	String dust_Error_S;
	String LPG_S;
	String LPG_Error_S;

	int temperature_state;
	int humidity_state;
	int CO2_state;
	int CO_state;
	int dust_state;
	int LPG_state;
} Data = {
	-999.0,
	-999.0,
	-999.0,
	-999.0,
	-999.0,
	-999.0,
	-999.0,
	-999.0,
	-999.0,
	-999.0,
	-999.0,
	-999.0,

	"-",
	"-",
	"-",
	"-",
	"-",
	"-",
	"-",
	"-",
	"-",
	"-",
	"-",
	"-",

	0,
	0,
	0,
	0,
	0,
	0
};


#pragma endregion

SoftwareSerial SoftTransmitter(sclPin, sdaPin, false, 90); // RX, TX
void setup() 
{
	Serial.begin(9600); 
	Serial1.begin(9600); //Инициализируем serial соединение для отладки
	SoftTransmitter.begin(9600);
	delay(10);

	if (SD.begin(SS))
	{
		Serial1.println("SD Card initialized."); //debug
		hasSD = true;
	}
	LoadSettings();

	pinMode(D2, INPUT); //Чием статус воспроизведения
	mp3_set_serial(SoftTransmitter);
	mp3_set_volume(22);

	DisplaySetup();


#pragma region ConnectToWifi
	WiFi.mode(WIFI_STA);
	delay(50);
	if (findWiFiAndConnect())
	{
		Serial1.println(""); //debug
		Serial1.println("WiFi connected"); //debug
		Serial1.print("IP address: "); //debug
		Serial1.println(WiFi.localIP()); //debug

		NetworkStatusDislpaySet(true);
	}
	else
	{
		NetworkStatusDislpaySet(false);
		WiFi.mode(WIFI_AP);
		WiFi.softAP("AirQuality");
	}
#pragma endregion
#pragma region ConnectToMQTT
	if ((!Settings.DisableMQTT) && (WiFi.mode(WIFI_STA)) && (WiFi.status() == WL_CONNECTED))
	{
		if (ConnectToMQTT())
		{
			MQTTStatusDislpaySet(true);
		}
		else
		{
			MQTTStatusDislpaySet(false);
		}
	}
	else
	{
		MQTTStatusDislpaySet(false);
	}
#pragma endregion

	HTTP_init();
}


 #pragma region MainLOOP
unsigned long check_perepol = 0;
bool perepol = false;
unsigned long cycles_counter = 0;
unsigned long mqtt_prev_zapros = 0;
void loop()
{
#pragma region EVERY LOOP START
	
	if ((WiFi.getMode() == 3) || ((WiFi.getMode() != 3) && (WiFi.status() != WL_CONNECTED)))
	{
		NetworkStatusDislpaySet(false);
	}
	else
	{
		NetworkStatusDislpaySet(true);
	}
	

	if ((!Settings.DisableMQTT) && (!MQTTClient.connected()) && (WiFi.status() == WL_CONNECTED))
	{
		if (ConnectToMQTT())
		{
			MQTTStatusDislpaySet(true);
		}
		else
		{
			MQTTStatusDislpaySet(false);
		}
	}
	else if(Settings.DisableMQTT)
	{
		MQTTStatusDislpaySet(false);
	}
	else if (MQTTClient.connected())
	{
		MQTTStatusDislpaySet(true);
	}
	else if (!MQTTClient.connected())
	{
		MQTTStatusDislpaySet(false);
	}

	if (check_perepol > millis()) //Проверка на переполнение счётчика милисекунд со старта контроллера
	{
		perepol = true;
		cycles_counter++;
	}

	if (Settings.AlarmOn && (queue.size() > 0) && (digitalRead(D2) == HIGH))
	{
		mp3_play(queue.shift());
	}

	nex.poll(); //Обрабатываем сообщения от LCD-дисплея
#pragma endregion

#pragma region LOOP PERIOD
	if (((!perepol) && (millis() - prev_zapros >= 500UL))
		|| ((perepol) && (UNSIGNED_LONG_MAX - check_perepol + millis() >= 500UL))) //Запрос данных раз в секунду
	{
		String temp = "";
		char ch;

		if (SoftTransmitter.available())
		{
			//unsigned long startrecive = millis();//debug

			while (SoftTransmitter.available())
			{
				ch = SoftTransmitter.read();
				temp += ch;
				if (ch == '/n')
				{
					while (SoftTransmitter.available())
					{
						SoftTransmitter.read();
					}
					break;
				}
				if (!(SoftTransmitter.available()) && (ch != '/n'))
				{
					delay(10);
				}
			}

			//Serial1.print(temp);//debug

			//Serial1.println("Start parce data");//debug
			//startrecive = millis();//debug

			ParseData(temp);

			//Serial1.print("End parce data: ");//debug
			//Serial1.println(millis() - startrecive);//debug
		}

		//Serial1.print("Free heap: ");//debug
		//Serial1.println(ESP.getFreeHeap());//debug

		//Serial1.print("Connected: ");//debug
		//Serial1.println(WiFi.isConnected());//debug

		//Serial1.print("Status: ");//debug
		//Serial1.println(WiFi.status());//debug

		prev_zapros = millis();
	}


	if (((!perepol) && (millis() - mqtt_prev_zapros >= 5000UL)) 
		|| ((perepol) && (UNSIGNED_LONG_MAX - check_perepol + millis() >= 5000UL))) //Debug
	{
		if (MQTTClient.connected()) SendToMQTT();


		if ((WiFi.getMode() == 1) && (WiFi.status() != WL_CONNECTED))
		{
			Serial1.println("Connection lost! Reconnect..."); //debug
			if (!findWiFiAndConnect())
			{
				NetworkStatusDislpaySet(false);
				WiFi.mode(WIFI_AP);
				WiFi.softAP("AirQuality");
			}
			else
			{
				NetworkStatusDislpaySet(true);
			}
		}

		mqtt_prev_zapros = millis();
	}
#pragma endregion

#pragma region EVERY LOOP END
	HTTP.handleClient();
	check_perepol = millis();
	perepol = false;
	MQTTClient.loop();
#pragma endregion
}

#pragma endregion

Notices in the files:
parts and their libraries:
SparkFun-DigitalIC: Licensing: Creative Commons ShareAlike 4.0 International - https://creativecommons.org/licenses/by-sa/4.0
